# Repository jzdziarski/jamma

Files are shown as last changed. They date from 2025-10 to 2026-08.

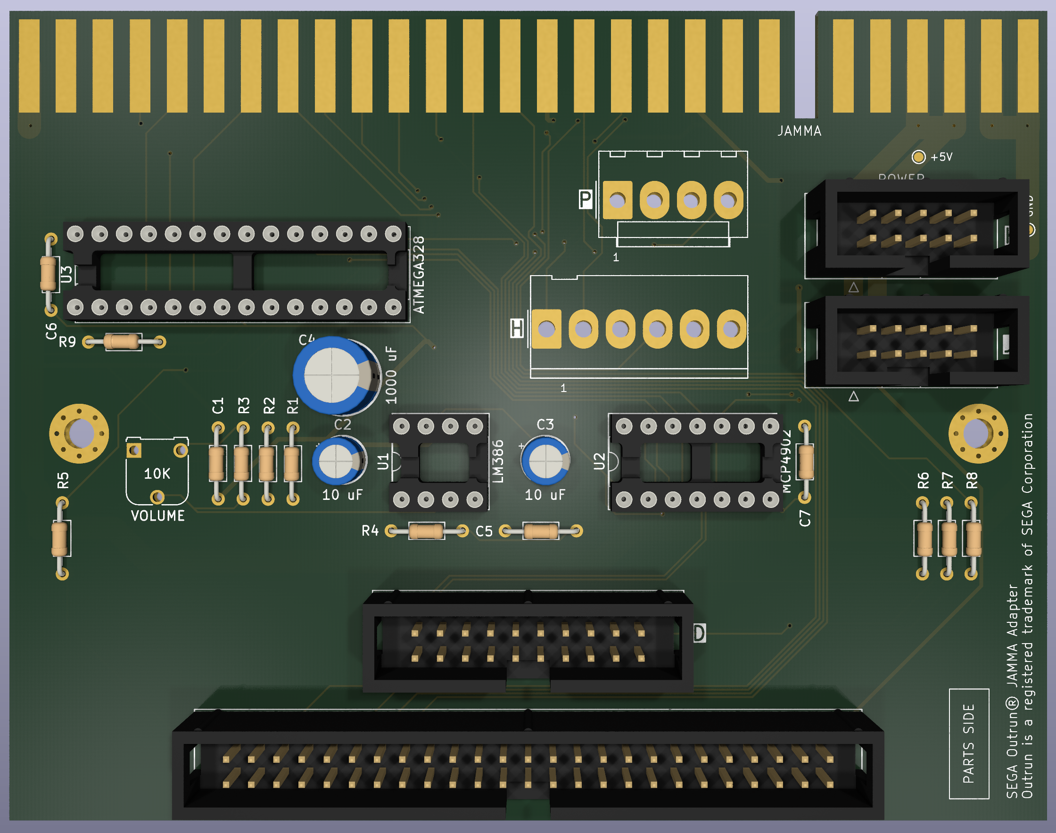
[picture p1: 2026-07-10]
Renderings/outrun_pcb_populated.png

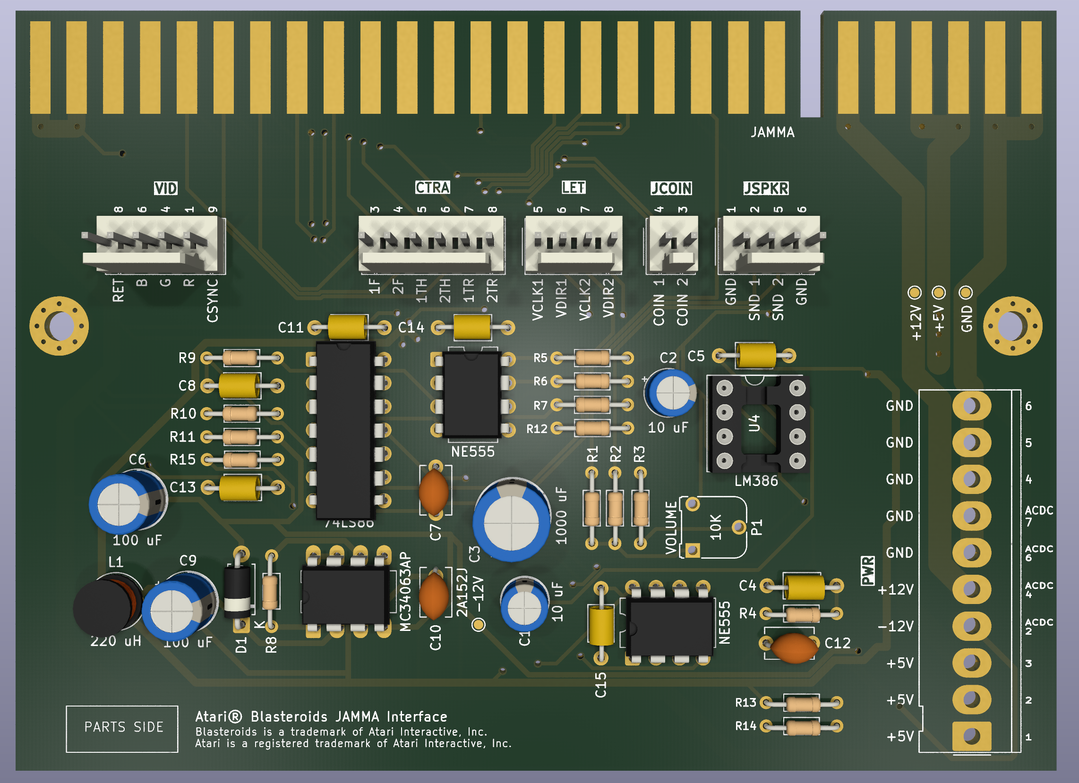
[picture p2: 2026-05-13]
Renderings/blasteroids_pcb_populated.png

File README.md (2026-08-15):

# /jamma
## Arcade JAMMA adapters and interface boards 
License: For non-commercial educational use only

|Subfolder|Description|
|---|---|
|CAD|PCB CAD Files|
|BOM|Bill of Materials (CSV)|
|Microcode|Microcontroller Code|
|Renderings|PCB Renderings|

## PCB Library
|Platform|Title|Tag|Status|
|---|---|---|---|
|Atari System I	|RoadBlasters|ROADBLASTERS_REV_0|Release|
|Atari System I |RoadBlasters|ROADBLASTERS_REV_1|Release|
|Atari System I/II/68K |*|ATARI_REV_0|Release|
|Atari System I/II/68K |*|ATARI_REV_1|Release|
|Blasteroids |Blasteroids|BLASTEROIDS_REV_0|Release|
|Midway MCR III	|Spy Hunter|SPY_HUNTER_REV_0|Release|
|Midway MCR III	|Spy Hunter|SPY_HUNTER_REV_1|Release|
|Midway MCR III |Spy Hunter|SPY_HUNTER_REV_1.1|Development|
|Midway MCR II	|TRON|TRON_REV_0|Release|
|Midway MCR II	|TRON|TRON_REV_1|Release|
|SEGA Super Scaler|Outrun|OUTRUN_REV_0|Release|
|SEGA Super Scaler|Super Hang-On|SUPER_HANG_ON_REV_0|Development|
|Williams System	|*|WILLIAMS_REV_0|Release|
|Williams System |*|WILLIAMS_REV_1|Development|
|Universal Edge	|*|UNIVERSAL_EDGE|Release|
|Universal Interface|*|UNIVERSAL_INTERFACE|Release|
|Universal Microcontroller Interface|*|UNIVERSAL_MICROCONTROLLER|Template|
|Universal Microcontroller Adapter|*|UNIVERSAL_MICROCONTROLLER_ADAPTER|Template|

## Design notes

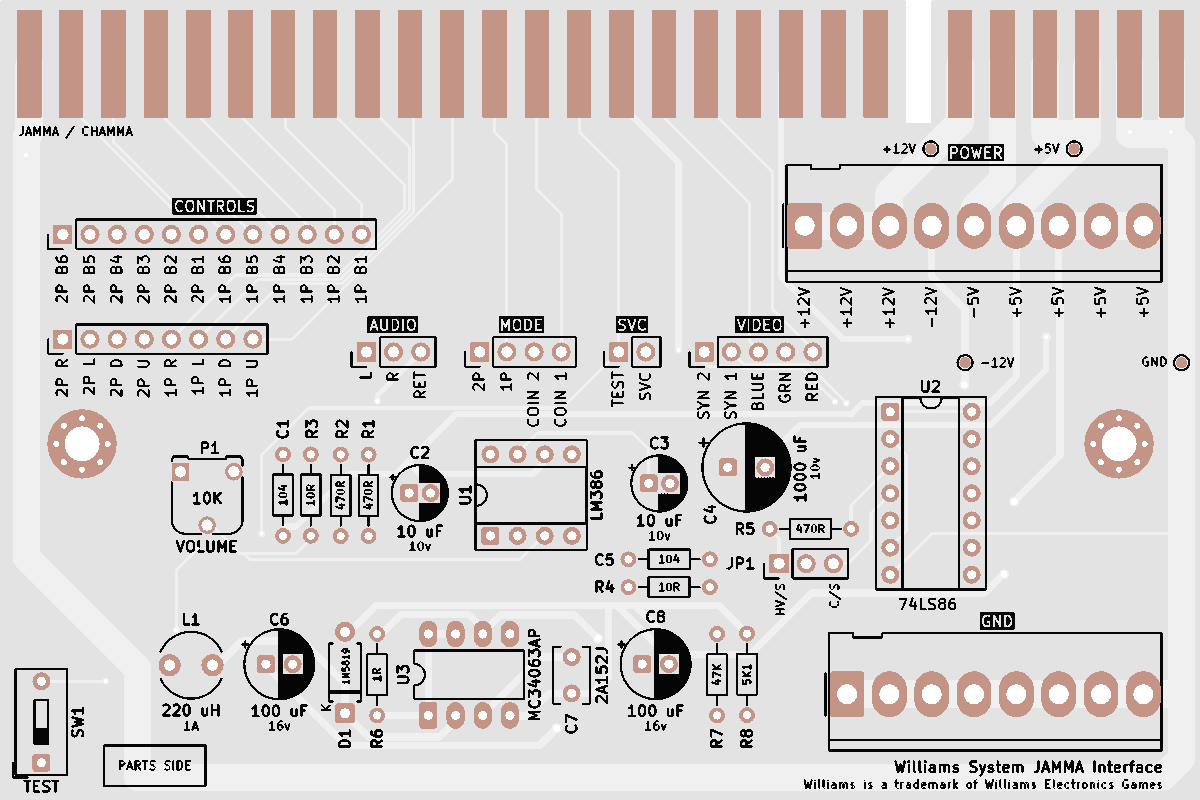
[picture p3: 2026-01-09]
Renderings/williams_pcb.png

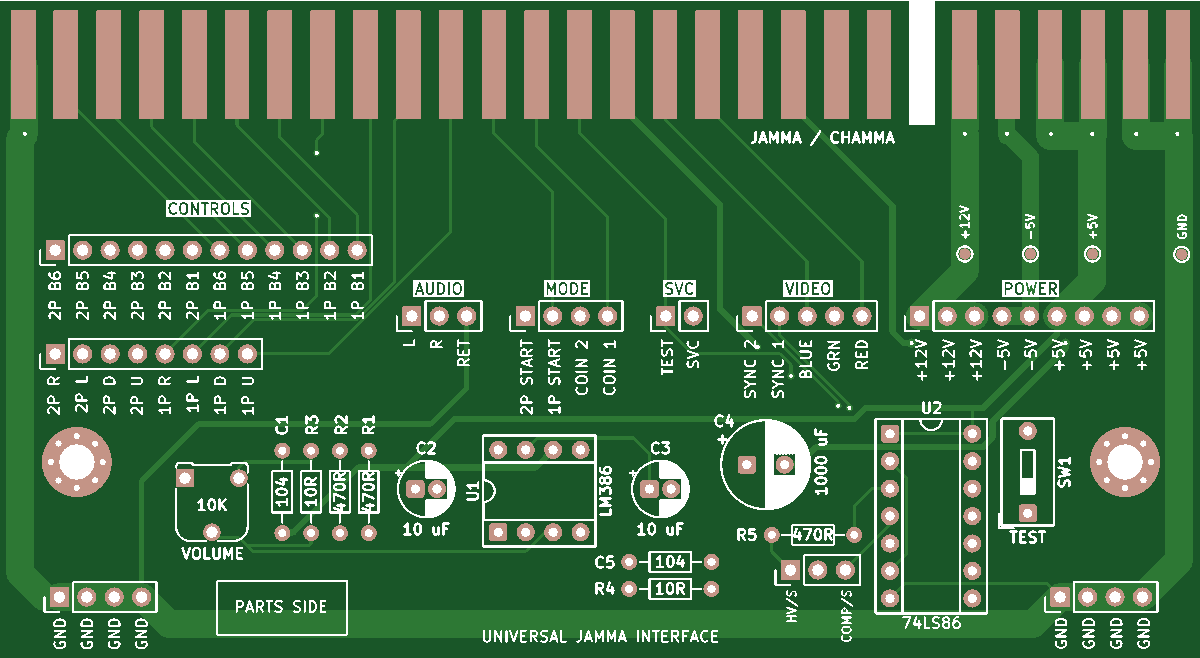
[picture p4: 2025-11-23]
Renderings/universal_jamma_pcb.png

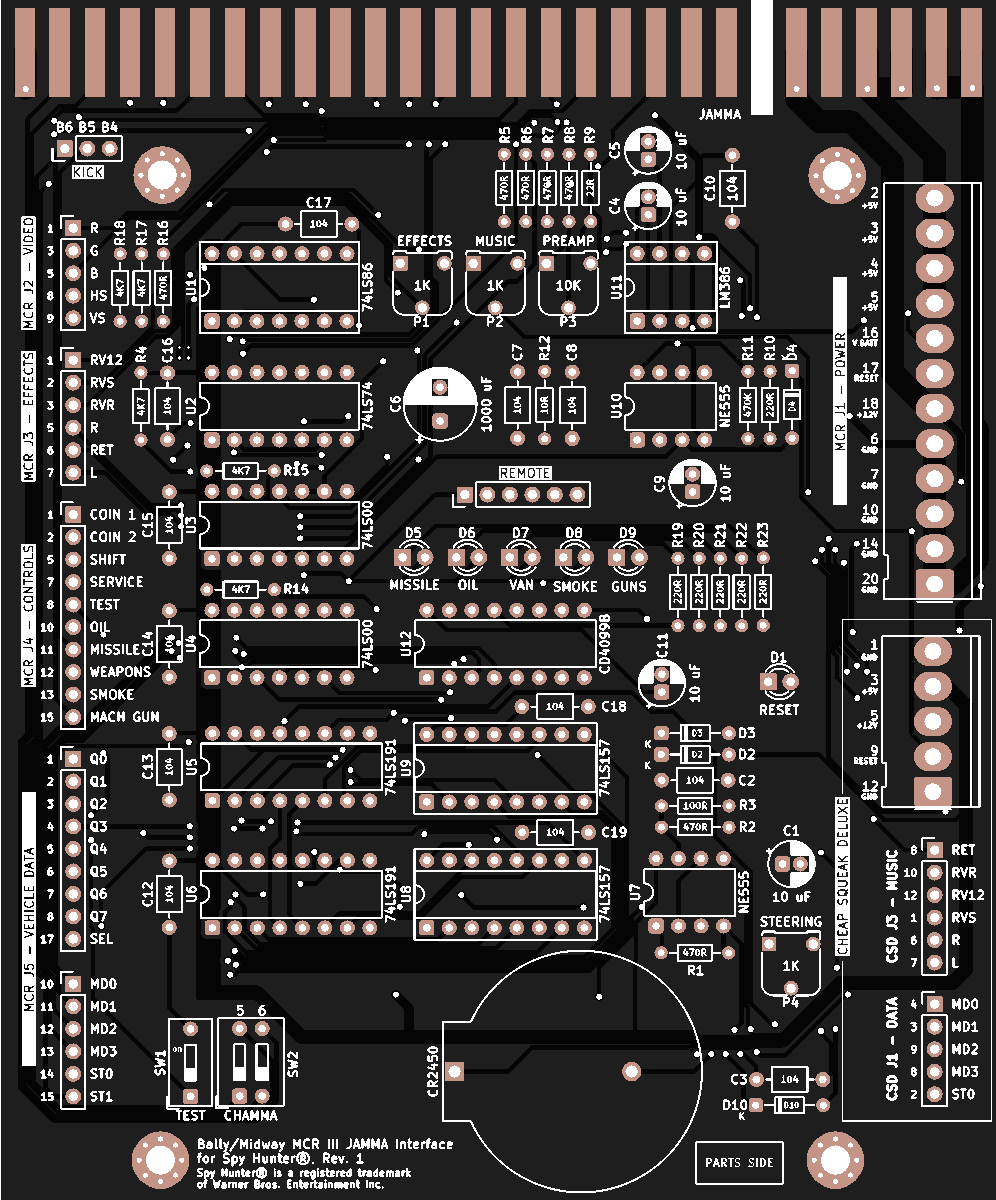
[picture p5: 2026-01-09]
Renderings/spy_hunter_pcb.png

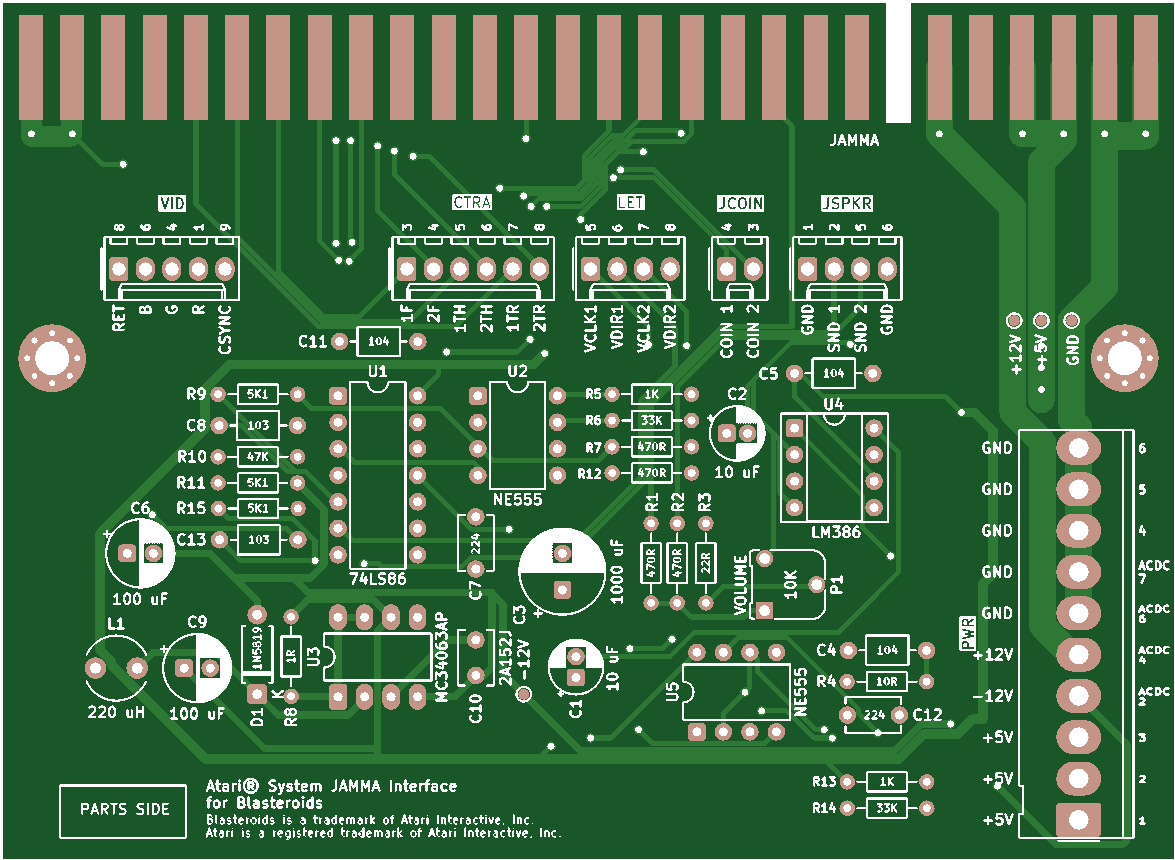
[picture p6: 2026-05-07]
Renderings/blasteroids_pcb.png

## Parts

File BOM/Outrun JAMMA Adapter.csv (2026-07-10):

Outrun JAMMA Adapter BOM
Index | Component | Manufacturer Part Number | Manufacturer Name | Description | Requested Quantity | Pack Quantity 1 | Pack Type 1 | Digi-Key Part Number | Unit Price | Extended Price | Link | Notes
1 | U1 | LM386N-1/NOPB | Texas Instruments | IC AMP CLASS AB MONO 325MW 8DIP | 1 | 1 | Tube | 296-44414-5-ND | 1.05 | $1.05 | https://www.digikey.com/en/products/detail/texas-instruments/LM386N-1-NOPB/6284
2 | U2 | MCP4902-E/P | Microchip Technology | IC DAC 8BIT 14-PDIP | 1 | 1 | Tube | MCP4902-E/P-ND | 1.84 | $1.84 | https://www.digikey.com/en/products/detail/microchip-technology/MCP4902-E-P/2332821
3 | U3 | ATMEGA328-PU | Microchip Technology | IC MCU 8BIT 32KB FLASH 28DIP | 1 | 1 | Tube | ATMEGA328-PU-ND | 2.63 | $2.63 | https://www.digikey.com/en/products/detail/microchip-technology/ATMEGA328-PU/2271026
4 | VOL | PT6KV-103A2020 | Amphenol Piher Sensing Systems | TRIMMER 10K OHM 0.1W PC PIN TOP | 1 | 1 | Bulk | 1993-PT6KV-103A2020-ND | 0.5 | $0.50 | https://www.digikey.com/en/products/detail/amphenol-piher-sensing-systems/PT6KV-103A2020/13244440
5 | R1 / R2 | CFM14JT470R | Stackpole Electronics Inc | RES 470 OHM 5% 1/4W AXIAL | 2 | 2 | Cut Tape (CT) | S470QCT-ND | 0.1 | $0.20 | https://www.digikey.com/en/products/detail/stackpole-electronics-inc/CFM14JT470R/1742224
6 | R3 | CF14JT2K20 | Stackpole Electronics Inc | RES 2.2K OHM 5% 1/4W AXIAL | 1 | 1 | Cut Tape (CT) | CF14JT2K20CT-ND | 0.16 | $0.16 | https://www.digikey.com/en/products/detail/stackpole-electronics-inc/CF14JT2K20/1741321
7 | R3 / R4 | CFM14JT10R0 | Stackpole Electronics Inc | RES 10 OHM 5% 1/4W AXIAL | 2 | 2 | Cut Tape (CT) | S10QCT-ND | 0.1 | $0.20 | https://www.digikey.com/en/products/detail/stackpole-electronics-inc/CFM14JT10R0/1742055
8 | R5-R8 | CFM14JT100R | Stackpole Electronics Inc | RES 100 OHM 5% 1/4W AXIAL | 4 | 4 | Cut Tape (CT) | S100QTR-ND | 0.1 | $0.40 | https://www.digikey.com/en/products/detail/stackpole-electronics-inc/CFM14JT100R/1742057
9 | R9 | CFM14JT10K0 | Stackpole Electronics Inc | RES 10K OHM 5% 1/4W AXIAL | 1 | 1 | Cut Tape (CT) | S10KQTR-ND | 0.1 | $0.10 | https://www.digikey.com/en/products/detail/stackpole-electronics-inc/CFM14JT10K0/1742061
10 | C1 / C5-C7 | C410C104K3R5TA7200 | KEMET | CAP CER 0.1UF 25V X7R AXIAL | 10 | 10 | Cut Tape (CT) | 399-C410C104K3R5TA7200CT-ND | 0.23 | $2.29 | https://www.digikey.com/en/products/detail/kemet/C410C104K3R5TA7200/14681403
11 | C2 / C3 | ESK106M010AC3AA | KEMET | CAP ALUM 10UF 20% 10V RADIAL TH | 2 | 2 | Bulk | 399-ESK106M010AC3AA-ND | 0.21 | $0.42 | https://www.digikey.com/en/products/detail/kemet/ESK106M010AC3AA/13176733
 | C4 | ESY108M010AH2EA | KEMET | CAP ALUM 1000UF 20% 10V RADIAL | 1 | 1 | Bulk | 399-6662-1-ND | 0.65 | $0.65 | https://www.digikey.com/en/products/detail/kemet/ESY108M010AH2EA/3083077
12
13 | U1S | 1-2199298-2 | TE Connectivity | CONN IC DIP SOCKET 8POS TIN | 1 | 1 | Bulk | A120347-ND | 0.22 | $0.22 | https://www.digikey.com/en/products/detail/te-connectivity-amp-connectors/1-2199298-2/5022039
 | U3S | 1-2199298-9 | TE Connectivity | CONN IC DIP SOCKET 28POS TIN1 | 1 | 1 | Bulk | A120353-ND | 1.01 | $1.01 | https://www.digikey.com/en/products/detail/te-connectivity-amp-connectors/1-2199298-9/5022045
14
15 | D | XG4A-2031 | Omron Electronics Inc | CONN HEADER VERT 20POS 2.54MM | 1 | 1 | Tray | OR885-ND | 2.12 | $2.12 | https://www.digikey.com/en/products/detail/omron-electronics-inc-emc-div/XG4A-2031/1787149
16 | G | XG4A-5031 | Omron Electronics Inc | CONN HEADER VERT 50POS 2.54MM | 1 | 1 | Tray | OR894-ND | 3.80 | $3.80 | https://www.digikey.com/en/products/detail/omron-electronics-inc-emc-div/XG4A-5031/1787154
17 | H | 26644060 | Molex | CONN HEADER VERT 6POS 3.96MM | 1 | 1 | Bulk | WM4655-ND | 0.76 | $0.76 | https://www.digikey.com/en/products/detail/molex/0026644060/2002014
18 | J, K | XG4A-1031 | Omron Electronics Inc | CONN HEADER VERT 10POS 2.54MM | 2 | 1 | Tray | OR880-ND | 1.41 | $2.82 | https://www.digikey.com/en/products/detail/omron-electronics-inc-emc-div/XG4A-1031/1787146
19 | P | 26644040 | Molex | CONN HEADER VERT 4POS 3.96MM | 1 | 1 | Bulk | 23-0026644040-ND | 1.29 | $1.29 | https://www.digikey.com/en/products/detail/molex/0026644040/2002012?s=N4IgTCBcDaIAxzANiQFlXDIC6BfIA

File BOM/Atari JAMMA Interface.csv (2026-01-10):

Atari System JAMMA Adapter
Index | Component | Manufacturer Part Number | Manufacturer Name | Description | Requested Quantity | Pack Quantity 1 | Pack Type 1 | Digi-Key Part Number | Unit Price | Extended Price | Link | Notes
1 | U1 | LM386N-1 | Texas Instruments | IC AMP CLASS AB MONO 325MW 8DIP | 1 | 1 | Tube | 296-44414-5-ND | 1.05 | $1.05 | https://www.digikey.com/en/products/detail/texas-instruments/LM386N-1-NOPB/6284
2 | U2 | SN74LS86AN | Texas Instruments | IC GATE XOR 4CH 2-INP 14DIP | 1 | 1 | Tube | 296-1669-5-ND | 0.75 | $0.75 | https://www.digikey.com/en/products/detail/texas-instruments/SN74LS86AN/277315
3 | U3 | MC34063AP | Texas Instruments | IC REG BUCK BOOST ADJ 1.5A 8PDIP | 1 | 1 | Tube | 296-17766-5-ND | 1.36 | $1.36 | https://www.digikey.com/en/products/detail/texas-instruments/MC34063AP/717432
4 | U4 | SN74LS04N | Texas Instruments | IC INVERTER 6CH 1-INP 14DIP | 1 | 1 | Tube | 296-1629-5-ND | 0.91 | $0.91 | https://www.digikey.com/en/products/detail/texas-instruments/SN74LS04N/277275
5 | SW1 | DS04-254-2L-01BK | Same Sky (Formerly CUI Devices) | SWITCH SLIDE DIP SPST 0.025A 24V | 1 | 1 | Tube | 2223-DS04-254-2L-01BK-ND | 0.65 | $0.65 | https://www.digikey.com/en/products/detail/same-sky-formerly-cui-devices/DS04-254-2L-01BK/11310830
6 |  | 22285364 | Molex | CONN HEADER VERT 36POS 2.54MM | 2 | 1 | Bag | WM50034-36-ND | 1.42 | 2.84 | https://www.digikey.com/en/products/detail/molex/0022285364/6167155
7 | POWER | 26481085 | Molex | CONN HEADER VERT 8POS 3.96MM | 1 | 1 | Bulk | WM50008-08-ND | 1.14 | 1.14 | https://www.digikey.com/en/products/detail/molex/0026481085/26767
8 | GND | 26481045 | Molex | CONN HEADER VERT 4POS 3.96MM | 2 | 1 | Bulk | WM50008-04-ND | 0.79 | 1.58 | https://www.digikey.com/en/products/detail/molex/0026481045/26759
9 | P1 | PT6KV-103A2020 | Amphenol Piher Sensing Systems | TRIMMER 10K OHM 0.1W PC PIN TOP | 1 | 1 | Bulk | 1993-PT6KV-103A2020-ND | 0.5 | $0.50 | https://www.digikey.com/en/products/detail/amphenol-piher-sensing-systems/PT6KV-103A2020/13244440
10 | R1 / R2 / R5 | CFM14JT470R | Stackpole Electronics Inc | RES 470 OHM 5% 1/4W AXIAL | 2 | 1 | Cut Tape (CT) | S470QCT-ND | 0.1 | $0.20 | https://www.digikey.com/en/products/detail/stackpole-electronics-inc/CFM14JT470R/1742224
11 | R3 | CFM14JT22R0 | Stackpole Electronics Inc | RES 22 OHM 5% 1/4W AXIAL | 1 | 1 | Cut Tape (CT) | S22QCT-ND | 0.1 | $0.10 | https://www.digikey.com/en/products/detail/stackpole-electronics-inc/CFM14JT22R0/1742137
12 | R4 | CFM14JT10R0 | Stackpole Electronics Inc | RES 10 OHM 5% 1/4W AXIAL | 1 | 1 | Cut Tape (CT) | S10QCT-ND | 0.1 | $0.10 | https://www.digikey.com/en/products/detail/stackpole-electronics-inc/CFM14JT10R0/1742055
13 | R6 | CFM14JT1R00 | Stackpole Electronics Inc | RES 1 OHM 5% 1/4W AXIAL | 1 | 1 | Cut Tape (CT) | S1QCT-ND | 0.1 | $0.10 | https://www.digikey.com/en/products/detail/stackpole-electronics-inc/cfm14jt1r00/1742027
14 | R7 | CFM14JT47K0 | Stackpole Electronics Inc | RES 47K OHM 5% 1/4W AXIAL | 1 | 1 | Cut Tape (CT) | S47KQCT-ND | 0.1 | $0.10 | https://www.digikey.com/en/products/detail/stackpole-electronics-inc/cfm14jt47k0/1742228
15 | R8 | CFM14JT5K10 | Stackpole Electronics Inc | RES 5.1K OHM 5% 1/4W AXIAL | 1 | 1 | Cut Tape (CT) | S5.1KQCT-ND | 0.1 | $0.10 | https://www.digikey.com/en/products/detail/stackpole-electronics-inc/CFM14JT5K10/1742231
16 | C1 / C5 | C410C104K3R5TA7200 | KEMET | CAP CER 0.1UF 25V X7R AXIAL | 2 | 1 | Cut Tape (CT) | 399-C410C104K3R5TA7200CT-ND | 0.23 | $0.46 | https://www.digikey.com/en/products/detail/kemet/C410C104K3R5TA7200/14681403
17 | C2 / C3 | ESK106M010AC3AA | KEMET | CAP ALUM 10UF 20% 10V RADIAL TH | 2 | 1 | Bulk | 399-ESK106M010AC3AA-ND | 0.21 | $0.42 | https://www.digikey.com/en/products/detail/kemet/ESK106M010AC3AA/13176733
18 | C4 | ESY108M010AH2EA | KEMET | CAP ALUM 1000UF 20% 10V RADIAL | 1 | 1 | Bulk | 399-6662-1-ND | 0.65 | $0.65 | https://www.digikey.com/en/products/detail/kemet/ESY108M010AH2EA/3083077
19 | C6 / C8 | ESK107M016AC3AA | KEMET | CAP ALUM 100UF 20% 16V RADIAL TH | 2 | 1 | Bulk | 399-6601-ND | 0.17 | $0.34 | https://www.digikey.com/en/products/detail/kemet/ESK107M016AC3AA/3083016
20 | C7 | QYX2A152JTP | Nichicon | CAP FILM 1500PF 5% 100VDC RADIAL | 1 | 1 | Bulk | 493-3478-ND | 0.42 | 0.42 | https://www.digikey.com/en/products/detail/nichicon/QYX2A152JTP/2117767
21 | L1 | RLB9012-221KL | Bourns, Inc. | FIXED IND 220UH 1A 650 MOHM TH | 1 | 1 | Bulk | RLB9012-221KL-ND | 0.58 | 0.58 | https://www.digikey.com/en/products/detail/bourns-inc/RLB9012-221KL/1969608
22 | D1 | 1N5819G | onsemi | DIODE SCHOTTKY 40V 1A AXIAL | 1 | 1 | Bulk | 1N5819GOS-ND | 0.23 | $0.23 | https://www.digikey.com/en/products/detail/onsemi/1N5819G/1474211

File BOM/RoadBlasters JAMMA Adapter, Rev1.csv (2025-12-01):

RoadBlasters JAMMA Adapter
Index | Component | Manufacturer Part Number | Manufacturer Name | Description | Requested Quantity | Pack Quantity 1 | Pack Type 1 | Digi-Key Part Number | Unit Price | Extended Price | Link | Notes
1 | U1 | SN74LS86AN | Texas Instruments | IC GATE XOR 4CH 2-INP 14DIP | 1 | 1 | Tube | 296-1669-5-ND | 0.75 | $0.75 | https://www.digikey.com/en/products/detail/texas-instruments/SN74LS86AN/277315
2 | U2 | NE555P | Texas Instruments | IC OSC SINGLE TIMER 100KHZ 8-DIP | 1 | 2 | Tube | 296-NE555P-ND | 0.51 | $0.51 | https://www.digikey.com/en/products/detail/texas-instruments/NE555P/277057
3 | U3 | MC34063AP | Texas Instruments | IC REG BUCK BOOST ADJ 1.5A 8PDIP | 1 | 1 | Tube | 296-17766-5-ND | 1.36 | $1.36 | https://www.digikey.com/en/products/detail/texas-instruments/MC34063AP/717432
4 | U4 | LM386N-1/NOPB | Texas Instruments | IC AMP CLASS AB MONO 325MW 8DIP | 1 | 1 | Tube | 296-44414-5-ND | 1.05 | $1.05 | https://www.digikey.com/en/products/detail/texas-instruments/LM386N-1-NOPB/6284
5 | SW1 | DS04-254-2L-01BK | Same Sky (Formerly CUI Devices) | SWITCH SLIDE DIP SPST 0.025A 24V | 1 | 1 | Tube | 2223-DS04-254-2L-01BK-ND | 0.65 | $0.65 | https://www.digikey.com/en/products/detail/same-sky-formerly-cui-devices/DS04-254-2L-01BK/11310830
6 | J102-J108 | 22284361 | Molex | CONN HEADER VERT 36POS 2.54MM | 1 | 1 | Bag | WM50017-36-ND | 1.23 | $1.23 | https://www.digikey.com/en/products/detail/molex/0022284361/313891
7 | P1 | PT6KV-103A2020 | Amphenol Piher Sensing Systems | TRIMMER 10K OHM 0.1W PC PIN TOP | 1 | 1 | Bulk | 1993-PT6KV-103A2020-ND | 0.5 | $0.50 | https://www.digikey.com/en/products/detail/amphenol-piher-sensing-systems/PT6KV-103A2020/13244440
11 | R1 / R2 / R7 | CFM14JT470R | Stackpole Electronics Inc | RES 470 OHM 5% 1/4W AXIAL | 2 | 2 | Cut Tape (CT) | S470QCT-ND | 0.1 | $0.20 | https://www.digikey.com/en/products/detail/stackpole-electronics-inc/CFM14JT470R/1742224 | 510 R acceptable
12 | R3 | CFM14JT22R0 | Stackpole Electronics Inc | RES 22 OHM 5% 1/4W AXIAL | 1 | 1 | Cut Tape (CT) | S22QCT-ND | 0.1 | $0.10 | https://www.digikey.com/en/products/detail/stackpole-electronics-inc/CFM14JT22R0/1742137
13 | R4 | CFM14JT10R0 | Stackpole Electronics Inc | RES 10 OHM 5% 1/4W AXIAL | 1 | 1 | Cut Tape (CT) | S10QCT-ND | 0.1 | $0.10 | https://www.digikey.com/en/products/detail/stackpole-electronics-inc/CFM14JT10R0/1742055
14 | R5 | CFM14JT1K00 | Stackpole Electronics Inc | RES 1K OHM 5% 1/4W AXIAL | 1 | 1 | Cut Tape (CT) | S1KQCT-ND | 0.1 | $0.10 | https://www.digikey.com/en/products/detail/stackpole-electronics-inc/CFM14JT1K00/1742111
15 | R6 | CFM14JT33K0 | Stackpole Electronics Inc | RES 33K OHM 5% 1/4W AXIAL | 1 | 1 | Cut Tape (CT) | S33KQCT-N | 0.1 | $0.10 | https://www.digikey.com/en/products/detail/stackpole-electronics-inc/cfm14jt33k0/1742191
16 | R9 / R11 | CFM14JT5K10 | Stackpole Electronics Inc | RES 5.1K OHM 5% 1/4W AXIAL | 2 | 2 | Cut Tape (CT) | S5.1KQCT-NDÊ | 0.1 | $0.20 | https://www.digikey.com/en/products/detail/stackpole-electronics-inc/CFM14JT5K10/1742231
17 | R8 | CFM14JT1R00 | Stackpole Electronics Inc | RES 1 OHM 5% 1/4W AXIAL | 1 | 1 | Cut Tape (CT) | S1QCT-ND | 0.1 | $0.10 | https://www.digikey.com/en/products/detail/stackpole-electronics-inc/cfm14jt1r00/1742027
18 | R10 | CFM14JT47K0 | Stackpole Electronics Inc | RES 47K OHM 5% 1/4W AXIAL | 1 | 1 | Cut Tape (CT) | S47KQCT-NDÊ | 0.1 | $0.10 | https://www.digikey.com/en/products/detail/stackpole-electronics-inc/cfm14jt47k0/1742228
19 | C1 / C2 | ESK106M010AC3AA | KEMET | CAP ALUM 10UF 20% 10V RADIAL TH | 2 | 2 | Bulk | 399-ESK106M010AC3AA-ND | 0.21 | $0.42 | https://www.digikey.com/en/products/detail/kemet/ESK106M010AC3AA/13176733
20 | C3 | ESY108M010AH2EA | KEMET | CAP ALUM 1000UF 20% 10V RADIAL | 1 | 1 | Bulk | 399-6662-1-ND | 0.65 | $0.65 | https://www.digikey.com/en/products/detail/kemet/ESY108M010AH2EA/3083077
21 | C4 / C5 | C410C104K3R5TA7200 | KEMET | CAP CER 0.1UF 25V X7R AXIAL | 10 | 10 | Cut Tape (CT) | 399-C410C104K3R5TA7200CT-ND | 0.23 | $2.29 | https://www.digikey.com/en/products/detail/kemet/C410C104K3R5TA7200/14681403
22 | C6 / C9 | ESK107M016AC3AA | KEMET | CAP ALUM 100UF 20% 16V RADIAL TH | 2 | 2 | Bulk | 399-6601-ND | 0.17 | $0.34 | https://www.digikey.com/en/products/detail/kemet/ESK107M016AC3AA/3083016
23 | C7 | C330C224J3H5TA91707301 | KEMET | CAP CER 0.22UF 25V X8R RADIAL | 1 | 1 | Cut Tape (CT) | 399-14397-1-ND | 1.1 | $1.10 | https://www.digikey.com/en/products/detail/kemet/C330C224J3H5TA91707301/6919003
24 | C8 | C430C103K3G5TA | KEMET | CAP CER 10000PF 25V C0G AXIAL | 1 | 1 | Bulk | C430C103K3G5TA-ND | 0.36 | $0.36 | https://www.digikey.com/en/products/detail/kemet/C430C103K3G5TA/6687833
25 | C10 | C322C152K5R5TA | KEMET | CAP CER 1500PF 50V X7R RADIAL | 1 | 1 | Bulk | 399-9800-ND | 0.31 | $0.31 | https://www.digikey.com/en/products/detail/kemet/C322C152K5R5TA/3726139 | Use film cap to reduce noise
26 | L1 | SBC1-221-391 | KEMET | FIXED IND 220UH 390MA 1.2 OHM TH | 1 | 1 | Bulk | 399-20737-ND | 0.69 | $0.69 | https://www.digikey.com/en/products/detail/kemet/SBC1-221-391/10062547
27 | D1 | 1N5819G | onsemi | DIODE SCHOTTKY 40V 1A AXIAL | 1 | 1 | Bulk | 1N5819GOS-ND | 0.23 | $0.23 | https://www.digikey.com/en/products/detail/onsemi/1N5819G/1474211
28 | U4S | 1-2199298-2 | TE Connectivity | CONN IC DIP SOCKET 8POS TIN | 1 | 1 | Bulk | A120347-ND | 0.22 | $0.22 | https://www.digikey.com/en/products/detail/te-connectivity-amp-connectors/1-2199298-2/5022039
29 | J101 | 26481105 | Molex | CONN HEADER VERT 10POS 3.96MM | 1 | 1 | Bulk | WM50008-10-ND | 1.33 | $1.33 | https://www.digikey.com/en/products/detail/molex/0026481105/26771

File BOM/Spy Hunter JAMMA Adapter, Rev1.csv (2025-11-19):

Spy Hunter JAMMA Adapter
Index | Component | Manufacturer Part Number | Manufacturer Name | Description | Requested Quantity | Pack Quantity 1 | Pack Type 1 | Digi-Key Part Number | Unit Price | Extended Price | Link | Notes
1 | U1 | SN74LS86AN | Texas Instruments | IC GATE XOR 4CH 2-INP 14DIP | 1 | 1 | Tube | 296-1669-5-ND | 0.75 | $0.75 | https://www.digikey.com/en/products/detail/texas-instruments/SN74LS86AN/277315
2 | U2 | SN74LS74AN | Texas Instruments | IC FF D-TYPE DOUBLE 1BIT 14PDIP | 1 | 1 | Tube | 296-1668-5-ND | 0.75 | $0.75 | https://www.digikey.com/en/products/detail/texas-instruments/SN74LS74AN/277314
3 | U3 U4 | SN74LS00N | Texas Instruments | IC GATE NAND 4CH 2-INP 14DIP | 2 | 1 | Tube | 296-1626-ND | 0.76 | $1.52 | https://www.digikey.com/en/products/detail/texas-instruments/SN74LS00N/277272
4 | U5 U6 | SN74LS191N | Texas Instruments | IC BINARY COUNTER 4-BIT 16DIP | 2 | 1 | Tube | 296-14886-5-ND | 1.58 | $3.16 | https://www.digikey.com/en/products/detail/texas-instruments/SN74LS191N/563041
5 | U7 U10 | NE555P | Texas Instruments | IC OSC SINGLE TIMER 100KHZ 8-DIP | 2 | 2 | Tube | 296-NE555P-ND | 0.51 | $1.02 | https://www.digikey.com/en/products/detail/texas-instruments/NE555P/277057
6 | U8 U9 | SN74LS157N | Texas Instruments | IC MULTIPLEXER 4 X 2:1 16-PDIP | 2 | 1 | Tube | 296-1645-5-ND | 1.02 | $2.04 | https://www.digikey.com/en/products/detail/texas-instruments/SN74LS157N/277291
7 | U11 | LM386N-1/NOPB | Texas Instruments | IC AMP CLASS AB MONO 325MW 8DIP | 1 | 1 | Tube | 296-44414-5-ND | 1.05 | $1.05 | https://www.digikey.com/en/products/detail/texas-instruments/LM386N-1-NOPB/6284
8 | U12 | CD4099BE | Texas Instruments | IC D-TYPE ADDR 1:8 16-PDIP | 1 | 1 | Tube | 296-2070-5-ND | 1.22 | $1.22 | https://www.digikey.com/en/products/detail/texas-instruments/CD4099BE/67333
9 | SW1 | DS04-254-2L-01BK | Same Sky (Formerly CUI Devices) | SWITCH SLIDE DIP SPST 0.025A 24V | 1 | 1 | Tube | 2223-DS04-254-2L-01BK-ND | 0.65 | $0.65 | https://www.digikey.com/en/products/detail/same-sky-formerly-cui-devices/DS04-254-2L-01BK/11310830
10 | SW2 | DS04-254-2L-02BK | Same Sky (Formerly CUI Devices) | SWITCH SLIDE DIP SPST 0.025A 24V | 1 | 1 | Tube | 2223-DS04-254-2L-02BK-ND | $0.62 | $0.62 | https://www.digikey.com/en/products/detail/same-sky-formerly-cui-devices-/DS04-254-2L-02BK/11310854
11 | MCR J2-J5, CSD J1, CSD J3, EXT, REMOTE | 22284361 | Molex | CONN HEADER VERT 36POS 2.54MM | 3 | 1 | Bag | WM50017-36-ND | 3.69 | $4.92 | https://www.digikey.com/en/products/detail/molex/0022284361/313891
12 | MCR J1 | 26481125 | Molex | CONN HEADER VERT 12POS 3.96MM | 1 | 1 | Bulk | WM50008-12-ND | 1.53 | $1.53 | https://www.digikey.com/en/products/detail/molex/0026481125/26775 | Gold plating 0416710011
13 | CSD J2 | 26481055 | Molex | CONN HEADER VERT 5POS 3.96MM | 1 | 1 | Bulk | WM50008-05-ND | 0.83 | $0.83 | https://www.digikey.com/en/products/detail/molex/0026481055/26761 | Gold plating 0416710027
14 | P1 P2 P4 | PT6KV-102A2020 | Amphenol Piher Sensing Systems | TRIMMER 1K OHM 0.1W PC PIN TOP | 3 | 1 | Bulk | 1993-1043-ND | 0.69 | $2.07 | https://www.digikey.com/en/products/detail/amphenol-piher-sensing-systems/PT6KV-102A2020/9555881
15 | P3 | PT6KV-103A2020 | Amphenol Piher Sensing Systems | TRIMMER 10K OHM 0.1W PC PIN TOP | 1 | 1 | Bulk | 1993-PT6KV-103A2020-ND | 0.5 | $0.50 | https://www.digikey.com/en/products/detail/amphenol-piher-sensing-systems/PT6KV-103A2020/13244440
16 | R1, R2, R5-R8, R16 | CFM14JT470R | Stackpole Electronics Inc | RES 470 OHM 5% 1/4W AXIAL | 7 | 1 | Cut Tape (CT) | S470QCT-ND | 0.1 | $0.70 | https://www.digikey.com/en/products/detail/stackpole-electronics-inc/CFM14JT470R/1742224 | 510 R acceptable
17 | R9 | CFM14JT22R0 | Stackpole Electronics Inc | RES 22 OHM 5% 1/4W AXIAL | 1 | 1 | Cut Tape (CT) | S22QCT-ND | 0.1 | $0.10 | https://www.digikey.com/en/products/detail/stackpole-electronics-inc/CFM14JT22R0/1742137
18 | R12 | CFM14JT10R0 | Stackpole Electronics Inc | RES 10 OHM 5% 1/4W AXIAL | 1 | 1 | Cut Tape (CT) | S10QCT-ND | 0.1 | $0.10 | https://www.digikey.com/en/products/detail/stackpole-electronics-inc/CFM14JT10R0/1742055
19 | R4, R14-R18 | CFM14JT4K70 | Stackpole Electronics Inc | RES 4.7K OHM 5% 1/4W AXIAL | 8 | 1 | Cut Tape (CT) | S4.7KQCT-ND | 0.1 | $0.80 | https://www.digikey.com/en/products/detail/stackpole-electronics-inc/CFM14JT4K70/1742213
20 | R11 | CFM14JT470K | Stackpole Electronics Inc | RES 470K OHM 5% 1/4W AXIAL | 1 | 1 | Cut Tape (CT) | S470KQCT-ND | 0.1 | $0.10 | https://www.digikey.com/en/products/detail/stackpole-electronics-inc/CFM14JT470K/1742226
21 | R3 | CFM14JT100R | Stackpole Electronics Inc | RES 100 OHM 5% 1/4W AXIAL | 1 | 1 | Cut Tape (CT) | S100QCT-ND | 0.1 | $0.10 | https://www.digikey.com/en/products/detail/stackpole-electronics-inc/CFM14JT100R/1742057
22 | R10, R19-R23 | CFM14JT220R | Stackpole Electronics Inc | RES 220 OHM 5% 1/4W AXIAL | 6 | 1 | Cut Tape (CT) | S220QCT-ND | 0.1 | $0.60 | https://www.digikey.com/en/products/detail/stackpole-electronics-inc/CFM14JT200R/1742132
23 | D1, D5-9 | LTL-307EE | Lite-On Inc. | LED RED CLEAR T-1 3/4 T/H | 6 | 1 | Bulk | 160-1701-ND | 0.19 | $1.14 | https://www.digikey.com/en/products/detail/liteon/LTL-307EE/140833
24 | D2 / D3 | 1N5817RLG | onsemi | DIODE SCHOTTKY 20V 1A AXIAL | 2 | 1 | Cut Tape (CT) | 1N5817RLGOSCT-ND | 0.41 | $0.82 | https://www.digikey.com/en/products/detail/onsemi/1N5817RLG/807250
25 | D4, D10 | 1N4148TR | onsemi | DIODE STANDARD 100V 200MA DO35 | 2 | 1 | Cut Tape (CT) | 1N4148FSCT-ND | 0.1 | $0.20 | https://www.digikey.com/en/products/detail/onsemi/1N4148TR/458811
26 | C1 C4 C5 C9 C11 | ESK106M010AC3AA | KEMET | CAP ALUM 10UF 20% 10V RADIAL TH | 5 | 1 | Bulk | 399-ESK106M010AC3AA-ND | 0.21 | $0.84 | https://www.digikey.com/en/products/detail/kemet/ESK106M010AC3AA/13176733
27 | C2 C3 C7 C8 C10, C12-C19 | C410C104K3R5TA7200 | KEMET | CAP CER 0.1UF 25V X7R AXIAL | 20 | 10 | Cut Tape (CT) | 399-C410C104K3R5TA7200CT-ND | 0.23 | $4.58 | https://www.digikey.com/en/products/detail/kemet/C410C104K3R5TA7200/14681403
28 | C6 | ESY108M010AH2EA | KEMET | CAP ALUM 1000UF 20% 10V RADIAL | 1 | 1 | Bulk | 399-6662-1-ND | 0.65 | $0.65 | https://www.digikey.com/en/products/detail/kemet/ESY108M010AH2EA/3083077
29 | CR2450 | 1053 | Keystone | BATT HOLDER COIN 24.5MM PC PIN | 1 | 1 | Bulk | 36-1053-ND | 1.42 | $1.42 | https://www.digikey.com/en/products/detail/keystone-electronics/1053/2745672

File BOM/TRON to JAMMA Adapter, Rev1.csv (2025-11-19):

TRON to JAMMA Adapter
Index | Component | Manufacturer Part Number | Manufacturer Name | Description | Requested Quantity | Pack Quantity 1 | Pack Type 1 | Digi-Key Part Number | Unit Price | Extended Price | Link | Notes
1 | U1 | SN74LS86AN | Texas Instruments | IC GATE XOR 4CH 2-INP 14DIP | 1 | 1 | Tube | 296-1669-5-ND | 0.75 | $0.75 | https://www.digikey.com/en/products/detail/texas-instruments/SN74LS86AN/277315
2 | U2A / U2B | SN74LS191N | Texas Instruments | IC BINARY COUNTER 4-BIT 16DIP | 2 |  | Tube | 296-14886-5-ND | 1.58 | $3.16 | https://www.digikey.com/en/products/detail/texas-instruments/SN74LS191N/563041
3 | U3 / U5 | NE555P | Texas Instruments | IC OSC SINGLE TIMER 100KHZ 8-DIP | 2 | 2 | Tube | 296-NE555P-ND | 0.51 | $1.02 | https://www.digikey.com/en/products/detail/texas-instruments/NE555P/277057
4 | U4 | LM386N-1/NOPB | Texas Instruments | IC AMP CLASS AB MONO 325MW 8DIP | 1 | 1 | Tube | 296-44414-5-ND | 1.05 | $1.05 | https://www.digikey.com/en/products/detail/texas-instruments/LM386N-1-NOPB/6284
5 | SW1 | DS04-254-2L-01BK | Same Sky (Formerly CUI Devices) | SWITCH SLIDE DIP SPST 0.025A 24V | 1 | 1 | Tube | 2223-DS04-254-2L-01BK-ND | 0.65 | $0.65 | https://www.digikey.com/en/products/detail/same-sky-formerly-cui-devices/DS04-254-2L-01BK/11310830
7 | JP1 / JP2 | 901310780 | Molex | CONN HEADER VERT 40POS 2.54MM | 1 | 1 | Bulk | WM8152-ND | 4.03 | $4.03 | https://www.digikey.com/en/products/detail/molex/0901310780/760866
8 | JP1S / JP2S | 60900213421 | Wurth Electronik | JUMPER W/TEST PNT 1X2PINS 2.54MM | 2 |  | Bag | 732-2678-ND | 0.28 | $0.56 | https://www.digikey.com/en/products/detail/w-rth-elektronik/60900213421/2508447
9 | J2 - J5 | 22284361 | Molex | CONN HEADER VERT 36POS 2.54MM | 1 | 1 | Bag | WM50017-36-ND | 1.23 | $1.23 | https://www.digikey.com/en/products/detail/molex/0022284361/313891
10 | J1 | 26605120 | Molex | CONN HEADER R/A 12POS 3.96MM | 1 | 1 | Bulk | 23-0026605120-ND | 0.94 | $0.94 | https://www.digikey.com/en/products/detail/molex/0026605120/190695 | Straight is 26604120
11 | P1 / P3 | PT6KV-102A2020 | Amphenol Piher Sensing Systems | TRIMMER 1K OHM 0.1W PC PIN TOP | 2 | 2 | Bulk | 1993-1043-ND | 0.69 | $1.38 | https://www.digikey.com/en/products/detail/amphenol-piher-sensing-systems/PT6KV-102A2020/9555881
12 | P2 | PT6KV-103A2020 | Amphenol Piher Sensing Systems | TRIMMER 10K OHM 0.1W PC PIN TOP | 1 | 1 | Bulk | 1993-PT6KV-103A2020-ND | 0.5 | $0.50 | https://www.digikey.com/en/products/detail/amphenol-piher-sensing-systems/PT6KV-103A2020/13244440
13 | R1 / R2 / R8 / R12 | CFM14JT470R | Stackpole Electronics Inc | RES 470 OHM 5% 1/4W AXIAL | 3 | 3 | Cut Tape (CT) | S470QCT-ND | 0.1 | $0.30 | https://www.digikey.com/en/products/detail/stackpole-electronics-inc/CFM14JT470R/1742224 | 510 R acceptable
14 | R3 | CFM14JT22R0 | Stackpole Electronics Inc | RES 22 OHM 5% 1/4W AXIAL | 1 | 1 | Cut Tape (CT) | S22QCT-ND | 0.1 | $0.10 | https://www.digikey.com/en/products/detail/stackpole-electronics-inc/CFM14JT22R0/1742137
15 | R4 | CFM14JT10R0 | Stackpole Electronics Inc | RES 10 OHM 5% 1/4W AXIAL | 1 | 1 | Cut Tape (CT) | S10QCT-ND | 0.1 | $0.10 | https://www.digikey.com/en/products/detail/stackpole-electronics-inc/CFM14JT10R0/1742055
16 | R5 / R11 | CFM14JT4K70 | Stackpole Electronics Inc | RES 4.7K OHM 5% 1/4W AXIAL | 2 | 1 | Cut Tape (CT) | S4.7KQCT-ND | 0.1 | $0.20 | https://www.digikey.com/en/products/detail/stackpole-electronics-inc/CFM14JT4K70/1742213
17 | R6 | CFM14JT470K | Stackpole Electronics Inc | RES 470K OHM 5% 1/4W AXIAL | 1 | 1 | Cut Tape (CT) | S470KQCT-ND | 0.1 | $0.10 | https://www.digikey.com/en/products/detail/stackpole-electronics-inc/CFM14JT470K/1742226
18 | R7 | CFM14JT100R | Stackpole Electronics Inc | RES 100 OHM 5% 1/4W AXIAL | 1 | 1 | Cut Tape (CT) | S100QCT-ND | 0.1 | $0.10 | https://www.digikey.com/en/products/detail/stackpole-electronics-inc/CFM14JT100R/1742057
19 | R9 | CFM14JT100K | Stackpole Electronics Inc | RES 100K OHM 5% 1/4W AXIAL | 1 | 1 | Cut Tape (CT) | S100KQCT-ND | 0.1 | $0.10 | https://www.digikey.com/en/products/detail/stackpole-electronics-inc/CFM14JT100K/1742059
20 | R10 | CFM14JT200R | Stackpole Electronics Inc | RES 200 OHM 5% 1/4W AXIAL | 2 | 2 | Cut Tape (CT) | S200QCT-ND | 0.1 | $0.20 | https://www.digikey.com/en/products/detail/stackpole-electronics-inc/CFM14JT200R/1742132
21 | D1 | 1N4148TR | onsemi | DIODE STANDARD 100V 200MA DO35 | 1 | 1 | Cut Tape (CT) | 1N4148FSCT-ND | 0.1 | $0.10 | https://www.digikey.com/en/products/detail/onsemi/1N4148TR/458811
22 | D2 / D3 | 1N5817RLG | onsemi | DIODE SCHOTTKY 20V 1A AXIAL | 2 | 2 | Cut Tape (CT) | 1N5817RLGOSCT-ND | 0.41 | $0.82 | https://www.digikey.com/en/products/detail/onsemi/1N5817RLG/807250
23 | D4 | LTL-307EE | Lite-On Inc. | LED RED CLEAR T-1 3/4 T/H | 1 | 1 | Bulk | 160-1701-ND | 0.19 | $0.19 | https://www.digikey.com/en/products/detail/liteon/LTL-307EE/140833
24 | C1, 3, 4, 8 | ESK106M010AC3AA | KEMET | CAP ALUM 10UF 20% 10V RADIAL TH | 4 | 4 | Bulk | 399-ESK106M010AC3AA-ND | 0.21 | $0.84 | https://www.digikey.com/en/products/detail/kemet/ESK106M010AC3AA/13176733
25 | C2, 6, 7, 9, 10, 11, 12 | C410C104K3R5TA7200 | KEMET | CAP CER 0.1UF 25V X7R AXIAL | 10 | 10 | Cut Tape (CT) | 399-C410C104K3R5TA7200CT-ND | 0.23 | $2.29 | https://www.digikey.com/en/products/detail/kemet/C410C104K3R5TA7200/14681403
26 | C5 | ESY108M010AH2EA | KEMET | CAP ALUM 1000UF 20% 10V RADIAL | 1 | 1 | Bulk | 399-6662-1-ND | 0.65 | $0.65 | https://www.digikey.com/en/products/detail/kemet/ESY108M010AH2EA/3083077
27 | U1S | 1-2199298-3 | TE Connectivity | CONN IC DIP SOCKET 14POS TIN | 1 | 1 | Bulk | A120348-ND | 0.23 | $0.23 | https://www.digikey.com/en/products/detail/te-connectivity-amp-connectors/1-2199298-3/5022040
28 | U2S | 1-2199298-8 | TE Connectivity | CONN IC DIP SOCKET 24POS TIN | 1 | 1 | Bulk | A120352-ND | 0.72 | $0.72 | https://www.digikey.com/en/products/detail/te-connectivity-amp-connectors/1-2199298-8/5022044
29 | U3S / U4S / U5S | 1-2199298-2 | TE Connectivity | CONN IC DIP SOCKET 8POS TIN | 3 | 3 | Bulk | A120347-ND | 0.22 | $0.66 | https://www.digikey.com/en/products/detail/te-connectivity-amp-connectors/1-2199298-2/5022039
30 | CR2450 | 1053 | Keystone | BATT HOLDER COIN 24.5MM PC PIN | Bulk | 36-1053-ND | 1.42 | $1.42 | https://www.digikey.com/en/products/detail/keystone-electronics/1053/2745672

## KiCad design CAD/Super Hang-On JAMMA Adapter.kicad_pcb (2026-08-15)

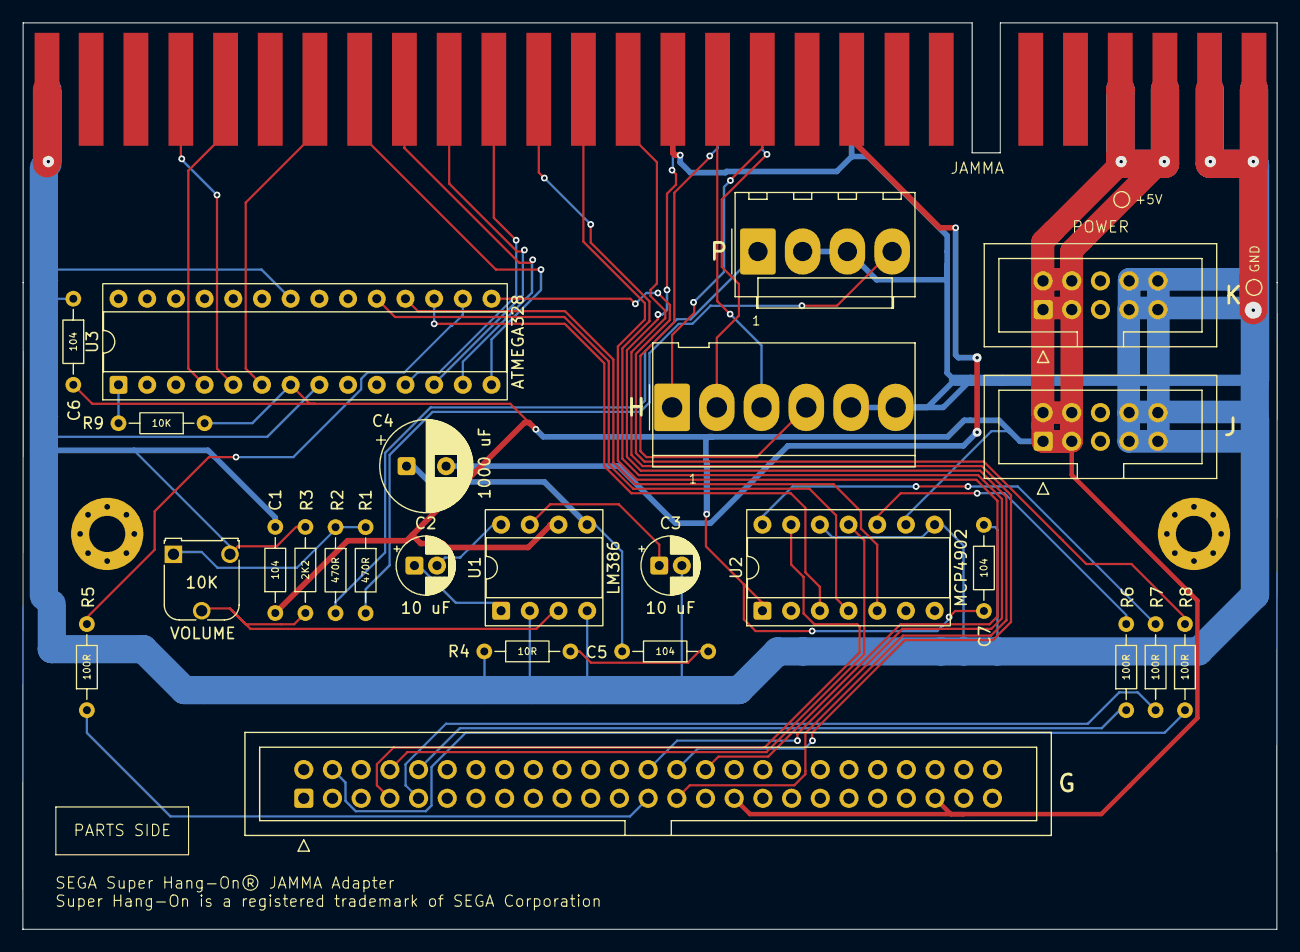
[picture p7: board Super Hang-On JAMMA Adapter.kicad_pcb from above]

Board: 2 copper layers, 111.0 x 80.2 mm, 28 parts (0 on the bottom side), 41 nets.

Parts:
+5V: TestPoint_Pad_D1.0mm
C1, C5, C6, C7: 104; R_Axial_DIN0204_L3.6mm_D1.6mm_P7.62mm_Horizontal
C2, C3: 10 uF; CP_Radial_D5.0mm_P2.00mm
C4: 1000 uF; CP_Radial_D8.0mm_P3.50mm
G: G; IDC-Header_2x25_P2.54mm_Vertical
GND: TestPoint_Pad_D1.0mm
H: H; Molex_KK-396_5273-06A_1x06_P3.96mm_Vertical
J: J; IDC-Header_2x05_P2.54mm_Vertical
JAMMA: HDR_JAMMA_56P_EDGE_CONNECTOR
K: K; IDC-Header_2x05_P2.54mm_Vertical
P: P; Molex_KK-396_A-41791-0004_1x04_P3.96mm_Vertical
R1, R2: 470R; R_Axial_DIN0204_L3.6mm_D1.6mm_P7.62mm_Horizontal
R3: 2K2; R_Axial_DIN0204_L3.6mm_D1.6mm_P7.62mm_Horizontal
R4: 10R; R_Axial_DIN0204_L3.6mm_D1.6mm_P7.62mm_Horizontal
R5, R6, R7, R8: 100R; R_Axial_DIN0204_L3.6mm_D1.6mm_P7.62mm_Horizontal
R9: 10K; R_Axial_DIN0204_L3.6mm_D1.6mm_P7.62mm_Horizontal
U1: LM386; DIP-8_W7.62mm_Socket
U2: MCP4902; DIP-14_W7.62mm_Socket
U3: ATMEGA328; DIP-28_W7.62mm_Socket
VOLUME: 10K; Potentiometer_Runtron_RM-065_Vertical

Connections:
1P_B1: JAMMA.22, U3.6
1P_B3: JAMMA.24, U3.4
1P_B4: JAMMA.25, U3.5
1P_D: JAMMA.19, U3.12
1P_L: JAMMA.20, U3.13
1P_R: JAMMA.21, U3.14
1P_START: G.26, JAMMA.17
1P_U: JAMMA.18, U3.11
+5V: +5V.1, C1.1, C6.2, C7.2, G.31, G.45, J.1, J.2, J.3, J.4, JAMMA.3, JAMMA.4, JAMMA.C, JAMMA.D, K.1, K.2, K.3, K.4, R9.1, U1.6, U2.1, U2.9, U3.7
ACCEL: G.9, R7.1
AUDIO_L: P.1, R2.2
AUDIO_MONO: R1.1, R2.1, VOLUME.1
AUDIO_R: P.4, R1.2
BRK: G.4, R8.1
C5_R4: C5.1, R4.1
COIN_1: G.30, JAMMA.16
GND: C1.2, C3.2, C6.1, C7.1, GND.1, H.5, H.6, J.7, J.8, J.9, J.10, JAMMA.1, JAMMA.2, JAMMA.14, JAMMA.28, JAMMA.A, JAMMA.B, JAMMA.L, JAMMA.f, K.7, K.8, K.9, K.10, P.2, P.3, R3.2, R4.2, U1.2, U1.4, U2.8, U2.12, U3.8, U3.22, VOLUME.3
PB1: R8.2, U3.15
PB2: R5.2, U3.16
PREAMP: R3.1, U1.3, VOLUME.2
PREAMP_OUT: C4.1, C5.2, U1.5
REFA: G.7, U2.13
REFB: G.8, U2.11
SERVICE: G.27, JAMMA.R
SPKR+: C4.2, JAMMA.10
STEER: G.10, R6.1
TEST: G.28, JAMMA.15
TURBO: G.25, R5.1
U1_BYPASS: C3.1, U1.7
U1_GAIN_P1: C2.1, U1.1
U1_GAIN_P8: C2.2, U1.8
U3_MISO_U2_SDI: U2.5, U3.18
U3_MOSI_U2_CS: U2.3, U3.17
U3_RSET: R9.2, U3.1
U3_SCK_U2_SCK: U2.4, U3.19
VID_B: H.3, JAMMA.13
VID_CSYNC: H.4, JAMMA.P
VID_G: H.2, JAMMA.N
VID_R: H.1, JAMMA.12
VOUTA: R7.2, U2.14
VOUTB: R6.2, U2.10

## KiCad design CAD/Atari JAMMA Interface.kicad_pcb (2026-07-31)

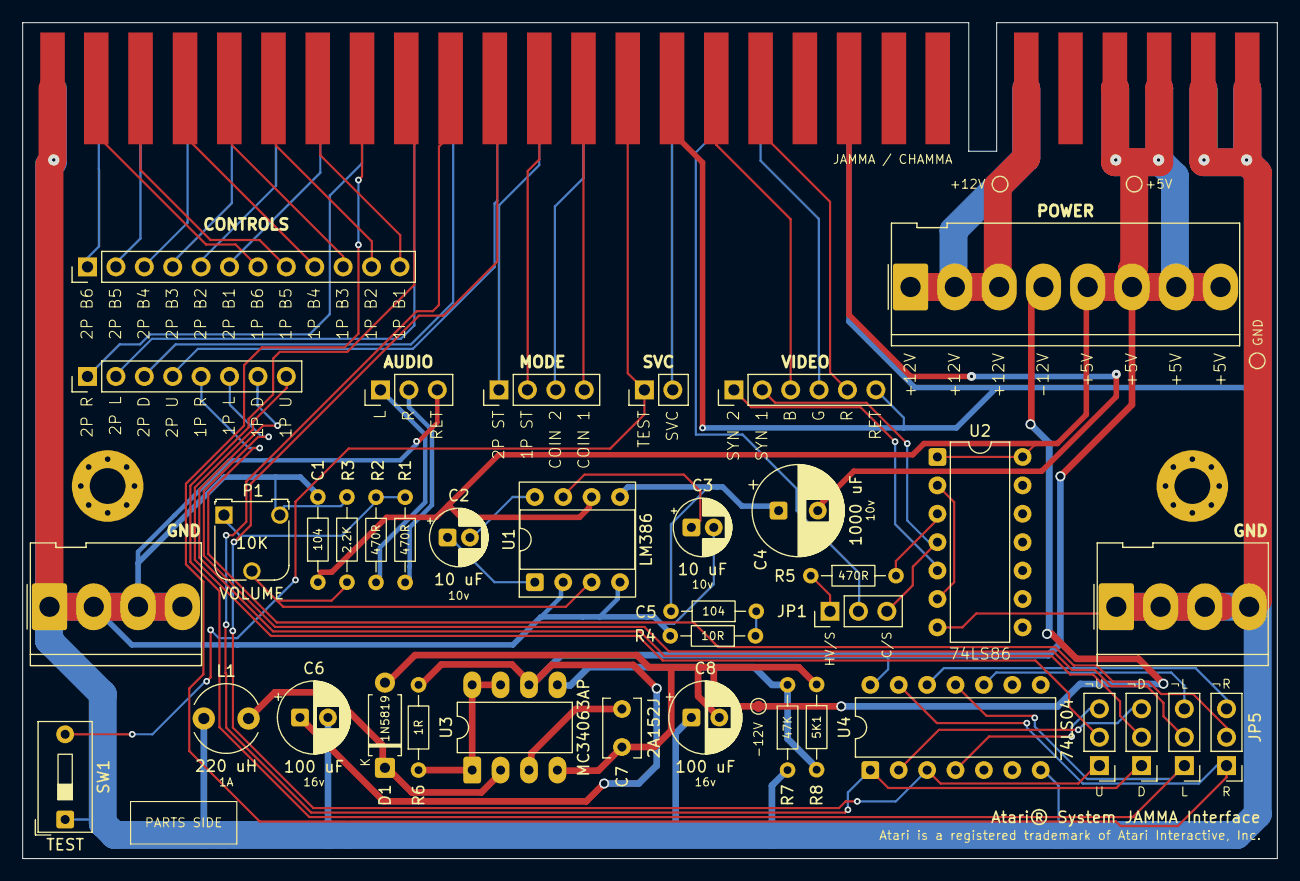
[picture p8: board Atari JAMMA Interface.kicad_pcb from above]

Board: 2 copper layers, 112.2 x 74.8 mm, 43 parts (0 on the bottom side), 61 nets.

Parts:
+5V, +12V: TestPoint_Pad_D1.0mm
-12V: TestPoint_Pad_D1.0mm
AUDIO: PinHeader_1x03_P2.54mm_Vertical
C1, C5: 104; R_Axial_DIN0204_L3.6mm_D1.6mm_P7.62mm_Horizontal
C2, C3: 10 uF; CP_Radial_D5.0mm_P2.00mm
C4: 1000 uF; CP_Radial_D8.0mm_P3.50mm
C6, C8: 100 uF; CP_Radial_D6.3mm_P2.50mm
C7: 2A152J; C_Disc_D5.1mm_W3.2mm_P3.4mm
CONTROLS: PinHeader_1x12_P2.54mm_Vertical
D1: 1N5819; D_A-405_P7.62mm_Horizontal
DIRECTIONALS: PinHeader_1x08_P2.54mm_Vertical
GND: TestPoint_Pad_D1.0mm
GND#2, GND#3: Molex_KK-396_5273-04A_1x04_P3.96mm_Vertical
HV/S: PinHeader_1x03_P2.54mm_Vertical
HV/S#2, HV/S#3, HV/S#4, HV/S#5: PinHeader_1x03_P2.54mm_Vertical
JAMMA / CHAMMA: HDR_JAMMA_56P_EDGE_CONNECTOR
L1: 220 uH; L_Radial_D6.0mm_P4.00mm
MODE: PinHeader_1x04_P2.54mm_Vertical
P1: 10K; Potentiometer_Runtron_RM-065_Vertical
POWER: Molex_KK-396_5273-08A_1x08_P3.96mm_Vertical
R1, R2, R5: 470R; R_Axial_DIN0204_L3.6mm_D1.6mm_P7.62mm_Horizontal
R3: 2.2K; R_Axial_DIN0204_L3.6mm_D1.6mm_P7.62mm_Horizontal
R4: 10R; R_Axial_DIN0204_L3.6mm_D1.6mm_P7.62mm_Horizontal
R6: 1R; R_Axial_DIN0204_L3.6mm_D1.6mm_P7.62mm_Horizontal
R7: 47K; R_Axial_DIN0204_L3.6mm_D1.6mm_P7.62mm_Horizontal
R8: 5K1; R_Axial_DIN0204_L3.6mm_D1.6mm_P7.62mm_Horizontal
SVC: PinHeader_1x02_P2.54mm_Vertical
TEST: SW1; SW_DIP_SPSTx01_Slide_9.78x4.72mm_W7.62mm_P2.54mm
U1: LM386; DIP-8_W7.62mm_Socket
U2: DIP-14_W7.62mm
U3: MC34063AP; DIP-8_W7.62mm_LongPads
U4: 74LS04; DIP-14_W7.62mm
VIDEO: PinHeader_1x06_P2.54mm_Vertical

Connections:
1P_!D: HV/S#5.3, U4.2
1P_!L: HV/S.3, U4.10
1P_!R: HV/S#2.3, U4.12
1P_!U: HV/S#3.3, U4.4
1P_B1: CONTROLS.12, JAMMA / CHAMMA.22
1P_B2: CONTROLS.11, JAMMA / CHAMMA.23
1P_B3: CONTROLS.10, JAMMA / CHAMMA.24
1P_B4: CONTROLS.9, JAMMA / CHAMMA.25
1P_B5: CONTROLS.8, JAMMA / CHAMMA.26
1P_B6: CONTROLS.7, JAMMA / CHAMMA.27
1P_D: HV/S#5.1, JAMMA / CHAMMA.19, U4.1
1P_D_OUT: DIRECTIONALS.7, HV/S#5.2
1P_L: HV/S.1, JAMMA / CHAMMA.20, U4.11
1P_L_OUT: DIRECTIONALS.6, HV/S.2
1P_R: HV/S#2.1, JAMMA / CHAMMA.21, U4.13
1P_R_OUT: DIRECTIONALS.5, HV/S#2.2
1P_START: JAMMA / CHAMMA.17, MODE.2
1P_U: HV/S#3.1, JAMMA / CHAMMA.18, U4.3
1P_U_OUT: DIRECTIONALS.8, HV/S#3.2
2P_B1: CONTROLS.6, JAMMA / CHAMMA.Z
2P_B2: CONTROLS.5, JAMMA / CHAMMA.a
2P_B3: CONTROLS.4, JAMMA / CHAMMA.b
2P_B4: CONTROLS.3, JAMMA / CHAMMA.c
2P_B5: CONTROLS.2, JAMMA / CHAMMA.d
2P_B6: CONTROLS.1, JAMMA / CHAMMA.e
2P_D: DIRECTIONALS.3, JAMMA / CHAMMA.W
2P_L: DIRECTIONALS.2, JAMMA / CHAMMA.X
2P_R: DIRECTIONALS.1, JAMMA / CHAMMA.Y
2P_START: JAMMA / CHAMMA.U, MODE.1
2P_U: DIRECTIONALS.4, JAMMA / CHAMMA.V
+5V: +5V.1, C1.1, C6.1, JAMMA / CHAMMA.3, JAMMA / CHAMMA.4, JAMMA / CHAMMA.C, JAMMA / CHAMMA.D, POWER.5, POWER.6, POWER.7, POWER.8, R6.2, U1.6, U2.1, U2.14, U3.6, U4.14
+12V: +12V.1, JAMMA / CHAMMA.6, JAMMA / CHAMMA.F, POWER.1, POWER.2, POWER.3
-12V: -12V.1, C7.1, C8.2, D1.2, POWER.4, R8.2, U3.4
AUDIO_L: AUDIO.1, R2.2
AUDIO_MONO: P1.1, R1.1, R2.1
AUDIO_R: AUDIO.2, R1.2
C5_R4: C5.1, R4.1
CINV_R10_R9: R7.2, R8.1, U3.5
COIN_1: JAMMA / CHAMMA.16, MODE.4
COIN_2: JAMMA / CHAMMA.T, MODE.3
GND: AUDIO.3, C1.2, C3.2, C6.2, C8.1, GND.1, GND#2.1, GND#2.2, GND#2.3, GND#2.4, GND#3.1, GND#3.2, GND#3.3, GND#3.4, JAMMA / CHAMMA.1, JAMMA / CHAMMA.2, JAMMA / CHAMMA.14, JAMMA / CHAMMA.28, JAMMA / CHAMMA.A, JAMMA / CHAMMA.B, JAMMA / CHAMMA.L, JAMMA / CHAMMA.f, L1.1, P1.3, R3.2, R4.2, R7.1, TEST.1, U1.2, U1.4, U2.7, U4.7, VIDEO.6
PREAMP: P1.2, R3.1, U1.3
PREAMP_OUT: C4.1, C5.2, U1.5
R8: R6.1, U3.1, U3.7, U3.8
SERVICE: JAMMA / CHAMMA.R, SVC.2
SPKR+: C4.2, JAMMA / CHAMMA.10
SWE: D1.1, L1.2, U3.2
TEST: JAMMA / CHAMMA.15, SVC.1, TEST.2
U3_CAP: C7.2, U3.3
U4_BYPASS: C3.1, U1.7
U4_GAIN_P1: C2.1, U1.1
U4_GAIN_P8: C2.2, U1.8
VID_B: JAMMA / CHAMMA.13, VIDEO.3
VID_CSYNC: HV/S#4.2, JAMMA / CHAMMA.P
VID_G: JAMMA / CHAMMA.N, VIDEO.4
VID_NXOR: HV/S#4.1, R5.1
VID_NXOR_R5: R5.2, U2.3
VID_R: JAMMA / CHAMMA.12, VIDEO.5
VID_SYN1: HV/S#4.3, U2.4, VIDEO.2
VID_SYN2: U2.5, VIDEO.1
VID_XOR: U2.2, U2.6

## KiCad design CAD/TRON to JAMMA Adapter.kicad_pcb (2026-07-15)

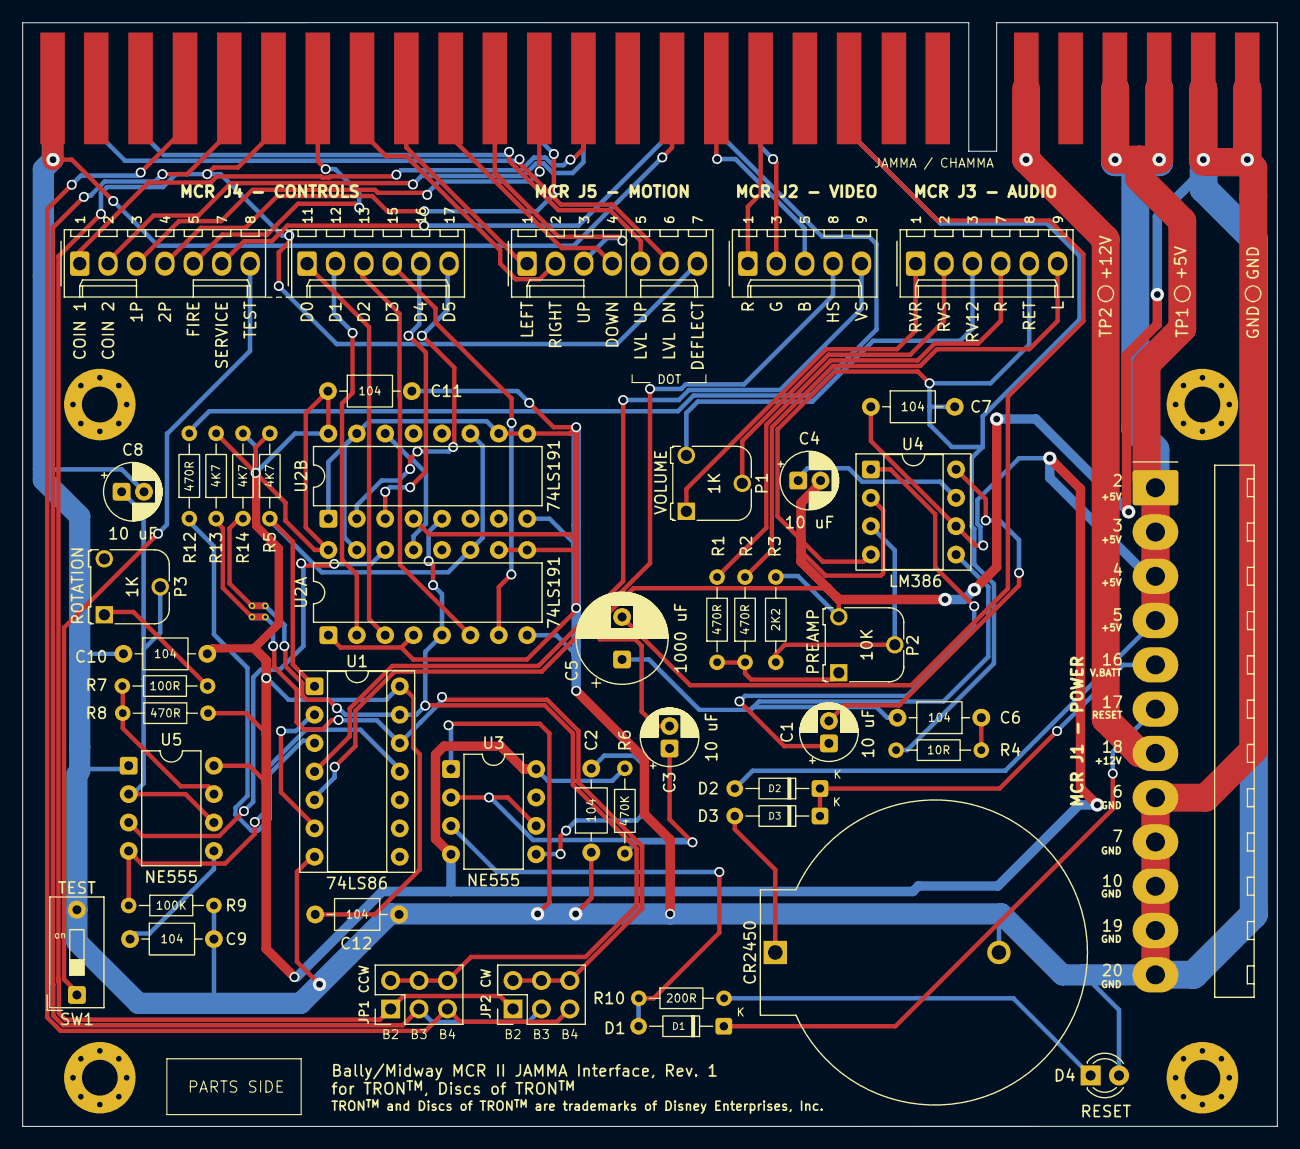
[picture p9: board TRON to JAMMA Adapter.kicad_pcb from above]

Board: 2 copper layers, 112.2 x 98.7 mm, 56 parts (0 on the bottom side), 63 nets.

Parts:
+5V: TP1; TestPoint_Pad_D1.0mm
+12V: TP2; TestPoint_Pad_D1.0mm
C1, C3, C4, C8: 10 uF; CP_Radial_D5.0mm_P2.00mm
C2, C6, C7, C9, C10, C11, C12: 104; C_Axial_L3.8mm_D2.6mm_P7.50mm_Horizontal
C5: 1000 uF; CP_Radial_D8.0mm_P3.80mm
CR2450: BatteryHolder_ComfortableElectronic_CH273-2450_1x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; BatteryHolder_ComfortableElectronic_CH273-2450_1x2450
D1: 1N4148; D_DO-34_SOD68_P7.62mm_Horizontal
D2, D3: 1N5817; D_DO-34_SOD68_P7.62mm_Horizontal
D4: LED; LED_D3.0mm
GND: GND; TestPoint_Pad_D1.0mm
JAMMA / CHAMMA: HDR_JAMMA_56P_EDGE_CONNECTOR
JP1 CCW, JP2 CW: PinHeader_2x03_P2.54mm_Vertical
MCRJ1: Molex_KK-396_A-41792-0012_1x12_P3.96mm_Horizontal
MCRJ2: Molex_KK-254_AE-6410-05A_1x05_P2.54mm_Vertical
MCRJ3, MCRJ4B: Molex_KK-254_AE-6410-06A_1x06_P2.54mm_Vertical
MCRJ4A, MCRJ5: Molex_KK-254_AE-6410-07A_1x07_P2.54mm_Vertical
P1, P3: 1K; Potentiometer_Runtron_RM-065_Vertical
P2: 10K; Potentiometer_Runtron_RM-065_Vertical
PMH1, PMH2, PMH3, PMH4: MountingHole_3.2mm_M3_Pad_Via
R1, R2, R8, R12: 470R; R_Axial_DIN0204_L3.6mm_D1.6mm_P7.62mm_Horizontal
R3: 2K2; R_Axial_DIN0204_L3.6mm_D1.6mm_P7.62mm_Horizontal
R4: 10R; R_Axial_DIN0204_L3.6mm_D1.6mm_P7.62mm_Horizontal
R5, R13, R14: 4K7; R_Axial_DIN0204_L3.6mm_D1.6mm_P7.62mm_Horizontal
R6: 470K; R_Axial_DIN0204_L3.6mm_D1.6mm_P7.62mm_Horizontal
R7: 100R; R_Axial_DIN0204_L3.6mm_D1.6mm_P7.62mm_Horizontal
R9: 100K; R_Axial_DIN0204_L3.6mm_D1.6mm_P7.62mm_Horizontal
R10: 200R; R_Axial_DIN0204_L3.6mm_D1.6mm_P7.62mm_Horizontal
TEST: SW1; SW_DIP_SPSTx01_Slide_9.78x4.72mm_W7.62mm_P2.54mm
U1: 74LS86; DIP-14_W7.62mm_Socket
U2A, U2B: 74LS191; DIP-16_W7.62mm
U3, U5: NE555; DIP-8_W7.62mm
U4: LM386; DIP-8_W7.62mm_Socket

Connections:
1P_B1: JAMMA / CHAMMA.22, MCRJ4A.5
1P_B2: JAMMA / CHAMMA.23, JP1 CCW.1, JP2 CW.1, MCRJ5.7
1P_B3: JAMMA / CHAMMA.24, JP1 CCW.3, JP2 CW.3
1P_B4: JAMMA / CHAMMA.25, JP1 CCW.5, JP2 CW.5
1P_B5: JAMMA / CHAMMA.d, MCRJ5.5
1P_B6: JAMMA / CHAMMA.e, MCRJ5.6
1P_D: JAMMA / CHAMMA.19, MCRJ5.4
1P_L: JAMMA / CHAMMA.20, MCRJ5.1
1P_R: JAMMA / CHAMMA.21, MCRJ5.2
1P_START: JAMMA / CHAMMA.17, MCRJ4A.3
1P_U: JAMMA / CHAMMA.18, MCRJ5.3
2P_START: JAMMA / CHAMMA.U, MCRJ4A.4
+5V: +5V.1, C7.1, C10.2, C11.1, C12.2, D2.2, JAMMA / CHAMMA.3, JAMMA / CHAMMA.4, JAMMA / CHAMMA.C, JAMMA / CHAMMA.D, MCRJ1.1, MCRJ1.2, MCRJ1.3, MCRJ1.4, R5.2, R6.2, R8.2, R13.2, R14.2, U1.14, U2A.16, U2B.16, U3.4, U3.8, U4.6, U5.8
+5V_R5: R5.1, U1.1, U2A.11, U2B.11
+12V_IN: +12V.1, JAMMA / CHAMMA.6, JAMMA / CHAMMA.F, MCRJ1.7
AUDIO_L: MCRJ3.6, R2.2
AUDIO_MONO: P2.1, R1.1, R2.1
AUDIO_OUT: C5.2, JAMMA / CHAMMA.10
AUDIO_PREAMP: P2.2, R3.1, U4.3
AUDIO_PREAMP_OUT: C5.1, C6.2, U4.5
AUDIO_R: MCRJ3.4, R1.2
BATTERY: CR2450.1, D3.2
C6_R4: C6.1, R4.1
CCW_IN: JP1 CCW.2, JP1 CCW.4, JP1 CCW.6, U1.13, U2A.5, U2B.5
CLK: U2A.14, U5.3
CLK_GATE: R9.1, U1.11, U5.4
COIN_1: JAMMA / CHAMMA.16, MCRJ4A.1
COIN_2: JAMMA / CHAMMA.T, MCRJ4A.2
CW_IN: JP2 CW.2, JP2 CW.4, JP2 CW.6, U1.12
E1: MCRJ4B.1, U2A.3
E2: MCRJ4B.2, U2A.2
E3: MCRJ4B.3, U2A.6
E4: MCRJ4B.4, U2A.7
E5: MCRJ4B.5, U2B.3
E6: MCRJ4B.6, U2B.2
GND: C2.1, C3.2, C4.2, C7.2, C8.2, C9.2, C10.1, C11.2, C12.1, CR2450.2, D4.2, GND.1, JAMMA / CHAMMA.1, JAMMA / CHAMMA.2, JAMMA / CHAMMA.14, JAMMA / CHAMMA.28, JAMMA / CHAMMA.A, JAMMA / CHAMMA.B, JAMMA / CHAMMA.L, JAMMA / CHAMMA.f, MCRJ1.8, MCRJ1.9, MCRJ1.10, MCRJ1.11, MCRJ1.12, MCRJ3.5, P2.3, R3.2, R4.2, R9.2, TEST.2, U1.7, U2A.1, U2A.4, U2A.8, U2A.9, U2A.10, U2A.15, U2B.1, U2B.4, U2B.8, U2B.9, U2B.10, U2B.15, U3.1, U4.2, U4.4, U5.1
R6_U3_P2_P6: C3.1, R6.1, U3.2, U3.6
RESET_5V: D1.2, R10.1, U3.3
RESET_5V_OUT: D1.1, MCRJ1.6
RESET_LED: D4.1, R10.2
SERVICE_SW: JAMMA / CHAMMA.R, MCRJ4A.6
TEST_SW: MCRJ4A.7, TEST.1
U1_P6_U1_P2: U1.2, U1.6
U3_CTRL: C2.2, U3.5
U4_BYPASS: C4.1, U4.7
U4_GAIN_P1: C1.1, U4.1
U4_GAIN_P8: C1.2, U4.8
U5_CTRL: C9.1, U5.5
U5_DIS: R7.1, R8.1, U5.7
U5_DIS_R2: P3.1, R7.2
U5_TRIG: C8.1, P3.2, U5.2, U5.6
U6_RCO: U2A.13, U2B.14
V.BATT: D2.1, D3.1, MCRJ1.5
VIDEO_B: JAMMA / CHAMMA.13, MCRJ2.3
VIDEO_G: JAMMA / CHAMMA.N, MCRJ2.2
VIDEO_HSYNC: MCRJ2.4, U1.5
VIDEO_RED: JAMMA / CHAMMA.12, MCRJ2.1
VIDEO_SYNC: JAMMA / CHAMMA.P, R12.2
VIDEO_SYNC_R12: R12.1, U1.3
VIDEO_VSYNC: MCRJ2.5, U1.4
VOL_GND: MCRJ3.3, P1.3
VOL_IN: MCRJ3.1, P1.1
VOL_OUT: MCRJ3.2, P1.2

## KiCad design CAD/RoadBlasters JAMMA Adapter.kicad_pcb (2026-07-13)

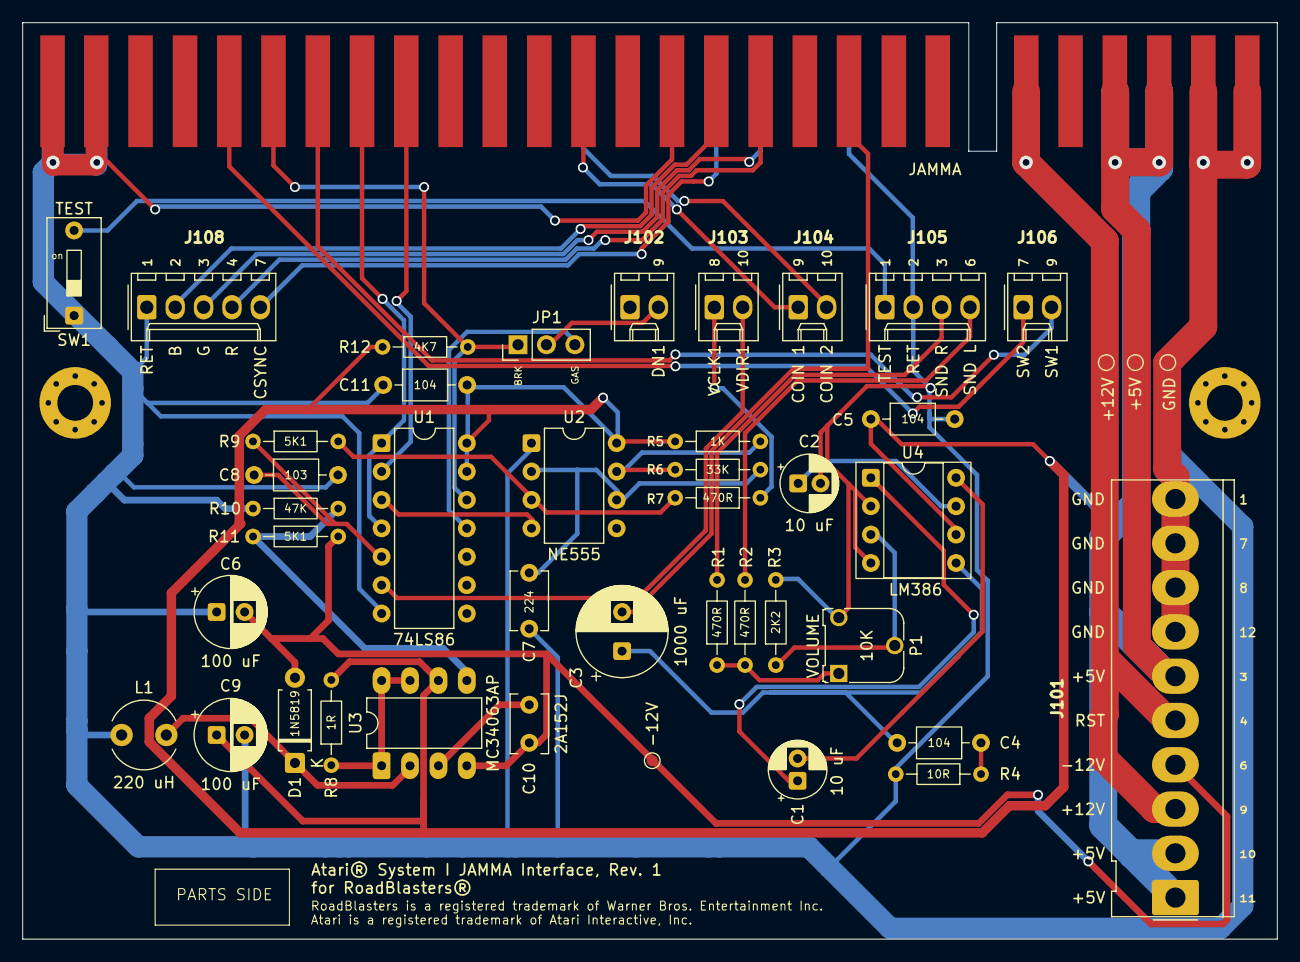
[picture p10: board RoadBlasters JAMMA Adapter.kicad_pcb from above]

Board: 2 copper layers, 112.2 x 82.0 mm, 46 parts (0 on the bottom side), 39 nets.

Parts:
+5V: TP2; TestPoint_Pad_D1.0mm
+12V: TP3; TestPoint_Pad_D1.0mm
-12V: TP4; TestPoint_Pad_D1.0mm
C1, C2: 10 uF; CP_Radial_D5.0mm_P2.00mm
C3: 1000 uF; CP_Radial_D8.0mm_P3.50mm
C4, C5, C11: 104; C_Axial_L3.8mm_D2.6mm_P7.50mm_Horizontal
C6, C9: 100 uF; CP_Radial_D6.3mm_P2.50mm
C7: 224; C_Disc_D5.1mm_W3.2mm_P5.00mm
C8: 103; C_Axial_L3.8mm_D2.6mm_P7.50mm_Horizontal
C10: 2A152J; C_Disc_D5.1mm_W3.2mm_P3.4mm
D1: 1N5819; D_A-405_P7.62mm_Horizontal
GND: TP1; TestPoint_Pad_D1.0mm
J101: Molex_KK-396_5273-10A_1x10_P3.96mm_Vertical
J102, J103, J104, J106: Molex_KK-254_AE-6410-02A_1x02_P2.54mm_Vertical
J105: Molex_KK-254_AE-6410-04A_1x04_P2.54mm_Vertical
J108: Molex_KK-254_AE-6410-05A_1x05_P2.54mm_Vertical
JAMMA: HDR_JAMMA_56P_EDGE_CONNECTOR
JP1: PinHeader_1x03_P2.54mm_Vertical
L1: 220 uH; L_Radial_D6.0mm_P4.00mm
P1: 10K; Potentiometer_Runtron_RM-065_Vertical
PMH1, PMH4: MountingHole_3.2mm_M3_Pad_Via
R1: R1; R_Axial_DIN0204_L3.6mm_D1.6mm_P7.62mm_Horizontal
R2, R7: 470R; R_Axial_DIN0204_L3.6mm_D1.6mm_P7.62mm_Horizontal
R3: 2K2; R_Axial_DIN0204_L3.6mm_D1.6mm_P7.62mm_Horizontal
R4: R_Axial_DIN0204_L3.6mm_D1.6mm_P7.62mm_Horizontal
R5: 1K; R_Axial_DIN0204_L3.6mm_D1.6mm_P7.62mm_Horizontal
R6: 33K; R_Axial_DIN0204_L3.6mm_D1.6mm_P7.62mm_Horizontal
R8: 1R; R_Axial_DIN0204_L3.6mm_D1.6mm_P7.62mm_Horizontal
R9, R11: 5K1; R_Axial_DIN0204_L3.6mm_D1.6mm_P7.62mm_Horizontal
R10: 47K; R_Axial_DIN0204_L3.6mm_D1.6mm_P7.62mm_Horizontal
R12: 4K7; R_Axial_DIN0204_L3.6mm_D1.6mm_P7.62mm_Horizontal
TEST: SW1; SW_DIP_SPSTx01_Slide_9.78x4.72mm_W7.62mm_P2.54mm
U1: 74LS86; DIP-14_W7.62mm
U2: NE555; DIP-8_W7.62mm
U3: MC34063AP; DIP-8_W7.62mm_LongPads
U4: LM386; DIP-8_W7.62mm_Socket

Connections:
1P_B1: J106.2, JAMMA.22
1P_B2: JAMMA.23, JP1.1, R12.2, U1.12
1P_B2_OUT: J102.2, JP1.2
1P_B3: J106.1, JAMMA.24
1P_L: JAMMA.20, U1.2
1P_R: JAMMA.21, U1.1, U1.4
!1P_B2: JP1.3, U1.11
+5V: +5V.1, C5.1, C9.1, C11.2, J101.1, J101.2, J101.6, JAMMA.3, JAMMA.4, JAMMA.C, JAMMA.D, R5.1, R8.2, R12.1, U1.13, U1.14, U2.8, U3.6, U4.6
+12V: +12V.1, J101.3, J101.5, JAMMA.6, JAMMA.F
-12V: -12V.1, C6.2, C10.1, D1.2, J101.4, R11.2, U3.4
AUDIO_L: J105.4, R2.2
AUDIO_MONO: P1.1, R1.1, R2.1
AUDIO_OUT: C3.2, JAMMA.10
AUDIO_PREAMP: P1.2, R3.1, U4.3
AUDIO_PREAMP_OUT: C3.1, C4.2, U4.5
AUDIO_R: J105.3, R1.2
C4_R4: C4.1, R4.1
CINV_R10_R9: R10.2, R11.1, U3.5
COIN_1: J104.1, JAMMA.16
COIN_2: J104.2, JAMMA.T
GND: C2.2, C5.2, C6.1, C7.1, C8.2, C9.2, C11.1, GND.1, J101.7, J101.8, J101.9, J101.10, J105.2, J108.1, JAMMA.1, JAMMA.2, JAMMA.14, JAMMA.27, JAMMA.28, JAMMA.A, JAMMA.B, JAMMA.L, JAMMA.e, JAMMA.f, L1.1, P1.3, R3.2, R4.2, R10.1, TEST.1, U1.7, U2.1, U4.2, U4.4
R8: R8.1, U3.1, U3.7, U3.8
SWE: D1.1, L1.2, U3.2
TEST_SW: J105.1, TEST.2
U2_DIS: R5.2, R6.1, U2.7
U2_RESET: U1.3, U2.4
U2_THR: C7.2, R6.2, U2.2, U2.6
U3_CAP: C10.2, U3.3
U4_BYPASS: C2.1, U4.7
U4_GAIN_P1: C1.1, U4.1
U4_GAIN_P8: C1.2, U4.8
VCLK1: R7.2, R9.2, U2.3
VCLK1_DELAYED: C8.1, R9.1, U1.5
VCLK1_OUT: J103.1, R7.1
VDIR1_OUT: J103.2, U1.6
VIDEO_B: J108.2, JAMMA.13
VIDEO_G: J108.3, JAMMA.N
VIDEO_R: J108.4, JAMMA.12
VIDEO_SYNC: J108.5, JAMMA.P

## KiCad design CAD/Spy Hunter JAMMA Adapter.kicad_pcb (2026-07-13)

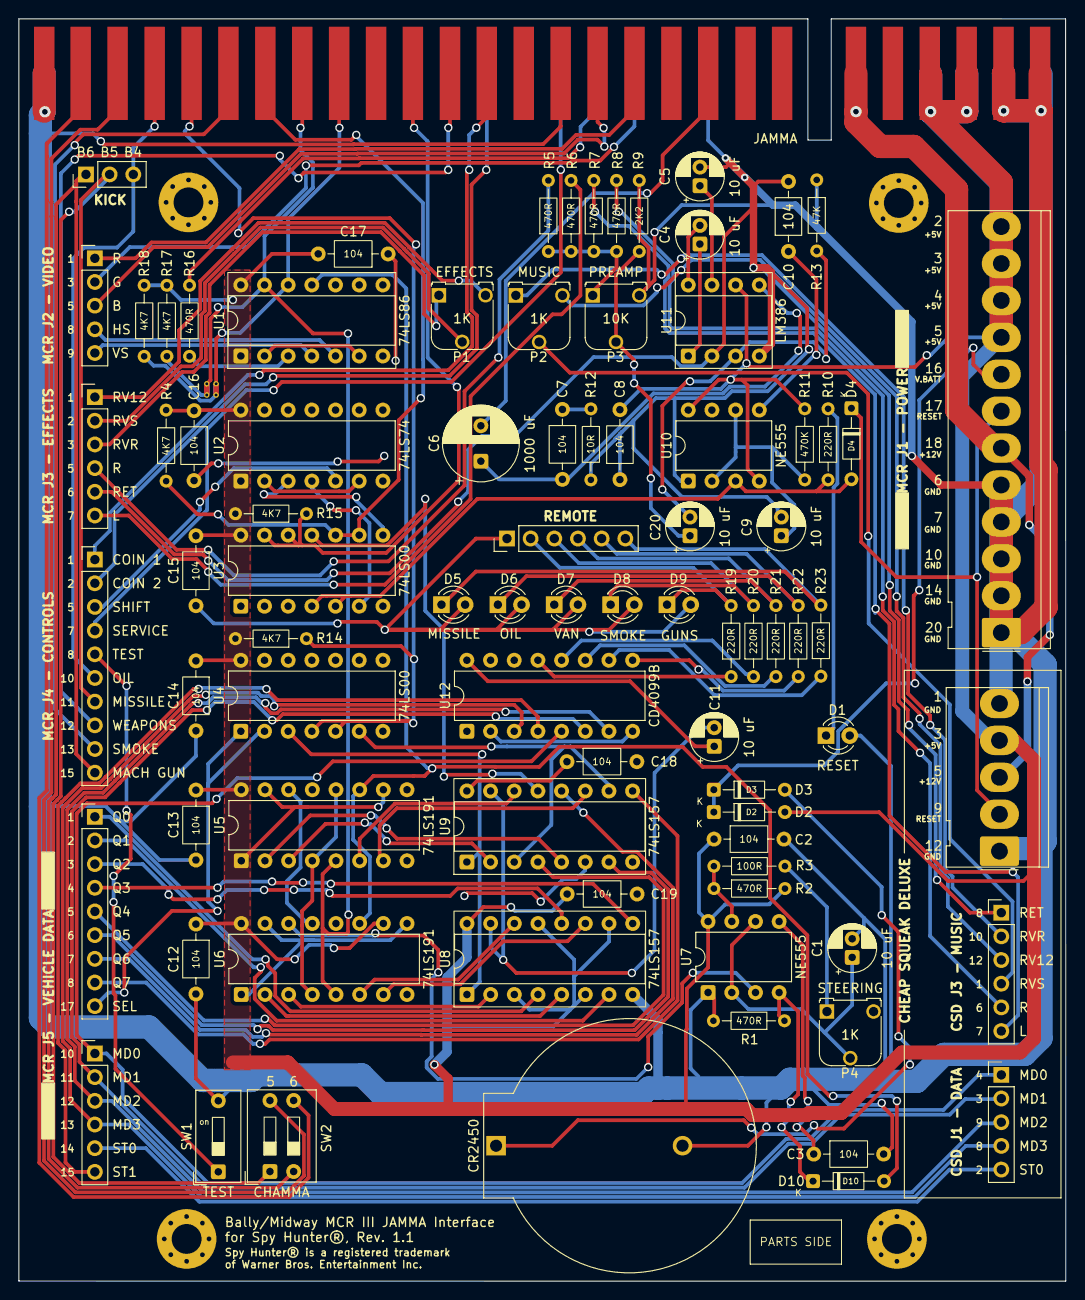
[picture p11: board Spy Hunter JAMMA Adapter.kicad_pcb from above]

Board: 2 copper layers, 112.3 x 135.4 mm, 88 parts (0 on the bottom side), 102 nets.

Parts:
C1, C4, C5, C9, C11, C20: 10 uF; CP_Radial_D5.0mm_P2.00mm
C2, C3, C7, C8, C10, C12, C13, C14, C15, C16, C17, C18, C19: 104; C_Axial_L3.8mm_D2.6mm_P7.50mm_Horizontal
C6: 1000 uF; CP_Radial_D8.0mm_P3.80mm
CR2450: BatteryHolder_ComfortableElectronic_CH273-2450_1x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; BatteryHolder_ComfortableElectronic_CH273-2450_1x2450
CSDJ1: PinHeader_1x05_P2.54mm_Vertical
CSDJ2: Molex_KK-396_5273-05A_1x05_P3.96mm_Vertical
CSDJ3: PinHeader_1x06_P2.54mm_Vertical
D1, D5, D6, D7, D8, D9: LED; LED_D3.0mm
D2, D3: 1N5817; D_DO-34_SOD68_P7.62mm_Horizontal
D4, D10: 1N4148; D_DO-34_SOD68_P7.62mm_Horizontal
JAMMA: HDR_JAMMA_56P_EDGE_CONNECTOR
KICK: PinHeader_1x03_P2.54mm_Vertical
MCR J5 - LAMPS: PinHeader_1x06_P2.54mm_Vertical
MCRJ1: Molex_KK-396_5273-12A_1x12_P3.96mm_Vertical
MCRJ2: PinHeader_1x05_P2.54mm_Vertical
MCRJ3: PinHeader_1x06_P2.54mm_Vertical
MCRJ4: PinHeader_1x10_P2.54mm_Vertical
MCRJ5: PinHeader_1x09_P2.54mm_Vertical
P1, P2, P4: 1K; Potentiometer_Runtron_RM-065_Vertical
P3: 10K; Potentiometer_Runtron_RM-065_Vertical
PMH1, PMH2, PMH3, PMH4: MountingHole_3.2mm_M3_Pad_Via
R1, R2, R5, R6, R7, R8, R16: 470R; R_Axial_DIN0204_L3.6mm_D1.6mm_P7.62mm_Horizontal
R3: 100R; R_Axial_DIN0204_L3.6mm_D1.6mm_P7.62mm_Horizontal
R4, R14, R15, R17, R18: 4K7; R_Axial_DIN0204_L3.6mm_D1.6mm_P7.62mm_Horizontal
R9: 2K2; R_Axial_DIN0204_L3.6mm_D1.6mm_P7.62mm_Horizontal
R10, R19, R20, R21, R22, R23: 220R; R_Axial_DIN0204_L3.6mm_D1.6mm_P7.62mm_Horizontal
R11: 470K; R_Axial_DIN0204_L3.6mm_D1.6mm_P7.62mm_Horizontal
R12: 10R; R_Axial_DIN0204_L3.6mm_D1.6mm_P7.62mm_Horizontal
R13: 47K; R_Axial_DIN0204_L3.6mm_D1.6mm_P7.62mm_Horizontal
REMOTE: PinHeader_1x06_P2.54mm_Vertical
SW2: SW_DIP_SPSTx02_Slide_9.78x7.26mm_W7.62mm_P2.54mm
TEST: SW1; SW_DIP_SPSTx01_Slide_9.78x4.72mm_W7.62mm_P2.54mm
U1: 74LS86; DIP-14_W7.62mm_Socket
U2: 74LS74; DIP-14_W7.62mm
U3, U4: 74LS00; DIP-14_W7.62mm
U5, U6: 74LS191; DIP-16_W7.62mm
U7, U10: NE555; DIP-8_W7.62mm
U8, U9: 74LS157; DIP-16_W7.62mm_Socket
U11: LM386; DIP-8_W7.62mm_Socket
U12: CD4099B; DIP-16_W7.62mm

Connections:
1P_B1: JAMMA.22, R4.1, U3.9, U3.10
1P_B2: JAMMA.23, MCRJ4.9
1P_B3: JAMMA.24, R14.1, U4.4, U4.5
1P_B4: JAMMA.25, KICK.3, MCRJ4.6
1P_B5: KICK.2, MCRJ4.7, SW2.1
1P_B5_CHAMMA: JAMMA.26, SW2.4
1P_B6: KICK.1, MCRJ4.10, SW2.2
1P_B6_CHAMMA: JAMMA.27, SW2.3
1P_GAS: U4.6, U9.3, U9.10
1P_LEFT: JAMMA.20, U1.12
1P_RIGHT: JAMMA.21, U1.13, U5.5, U6.5
1P_START: JAMMA.17, MCRJ4.8
1P_TURBO: U3.11, U9.13
1P_U: JAMMA.18, R15.1, U3.12, U3.13
!RST: U2.4, U3.6
!SEL: U4.3, U8.1, U9.1
!SHIFT_LATCH: U2.2, U2.6
+5V: C2.1, C8.2, C11.1, C12.1, C13.1, C14.1, C15.1, C16.1, C17.2, C18.1, C19.1, CSDJ2.4, D2.2, JAMMA.3, JAMMA.4, JAMMA.C, JAMMA.D, MCRJ1.9, MCRJ1.10, MCRJ1.11, MCRJ1.12, R2.2, R4.2, R11.2, R14.2, R15.2, R17.2, R18.2, U1.1, U1.14, U2.1, U2.14, U3.14, U4.14, U5.1, U5.10, U5.15, U5.16, U6.10, U6.16, U7.8, U8.3, U8.6, U8.10, U8.13, U8.16, U9.6, U9.16, U10.4, U10.8, U11.6, U12.16
+5V_RST: CSDJ2.2, D4.1, MCRJ1.7
+12V: CSDJ2.3, JAMMA.6, JAMMA.F, MCRJ1.6
AUDIO_MONO: P3.1, R5.1, R6.1, R7.1, R8.1
AUDIO_OUT: C6.2, JAMMA.10
AUDIO_PREAMP: C20.1, P3.2, R9.1
AUDIO_PREAMP_COUPLED: C20.2, R13.2, U11.3
AUDIO_PREAMP_OUT: C6.1, C7.2, U11.5
BATT+: CR2450.1, D3.2
C7_R12: C7.1, R12.1
CLK: U6.14, U7.3
CLK_GATE: D10.2, U1.11, U5.11, U6.11
COIN_1: JAMMA.16, MCRJ4.1
COIN_2: JAMMA.T, MCRJ4.2
D5: D5.1, R23.2, REMOTE.6
D6: D6.1, R22.2, REMOTE.5
D7: D7.1, R21.2, REMOTE.4
D8: D8.1, R20.2, REMOTE.3
D9: D9.1, R19.2, REMOTE.2
EFFECTS_L: MCRJ3.6, R6.2
EFFECTS_R: MCRJ3.4, R5.2
EFFECTS_RV12: MCRJ3.1, P1.3
EFFECTS_RVR: MCRJ3.3, P1.1
EFFECTS_RVS: MCRJ3.2, P1.2
GND: C1.2, C2.2, C3.2, C5.2, C8.1, C9.2, C10.2, C11.2, C12.2, C13.2, C14.2, C15.2, C16.2, C17.1, C18.2, C19.2, CR2450.2, CSDJ2.1, CSDJ2.5, CSDJ3.1, D1.2, D5.2, D6.2, D7.2, D8.2, D9.2, JAMMA.1, JAMMA.2, JAMMA.14, JAMMA.28, JAMMA.A, JAMMA.B, JAMMA.L, JAMMA.f, MCRJ1.1, MCRJ1.2, MCRJ1.3, MCRJ1.4, MCRJ1.5, MCRJ3.5, P3.3, R1.2, R9.2, R12.2, R13.1, REMOTE.1, TEST.2, U1.7, U2.7, U3.7, U4.7, U5.8, U5.9, U6.1, U6.8, U6.9, U6.15, U7.1, U8.8, U8.15, U9.8, U9.15, U10.1, U11.2, U11.4, U12.2, U12.8
J5_ST0: CSDJ1.5, MCR J5 - LAMPS.5
MAXMIN_CTEN: U5.4, U5.12, U6.4
MUSIC_L: CSDJ3.6, R7.2
MUSIC_R: CSDJ3.5, R8.2
MUSIC_RV12: CSDJ3.3, P2.3
MUSIC_RVR: CSDJ3.2, P2.1
MUSIC_RVS: CSDJ3.4, P2.2
Q0: MCRJ5.1, U8.4
Q1: MCRJ5.2, U8.7
Q2: MCRJ5.3, U8.12
Q3: MCRJ5.4, U8.9
Q4: MCRJ5.5, U9.4
Q5: MCRJ5.6, U9.7
Q6: MCRJ5.7, U9.12
Q7: MCRJ5.8, U9.9
RST: D4.2, R10.1, U3.4, U3.5, U10.3
RST_LED: D1.1, R10.2
SEL: MCRJ5.9, U4.1, U4.2
SERVICE_SW: JAMMA.R, MCRJ4.4
SHIFT_LATCH: MCRJ4.3, U2.5
TEST_SW: MCRJ4.5, TEST.1
U2_CLK: U2.3, U3.8
U6_RCO: U5.14, U6.13
U7_CTL: C3.1, U7.5
U7_DIS: R2.1, R3.1, U7.7
U7_DIS_P4_1: P4.1, R3.2
U7_RESET: D10.1, R1.1, U7.4
U7_TRIG: C1.1, P4.2, U7.2, U7.6
U8_I0a: U6.3, U8.2
U8_I0b: U6.2, U8.5
U8_I0c: U6.6, U8.14
U8_I0d: U6.7, U8.11
U9_I0a: U5.3, U9.2
U9_I0b: U5.2, U9.5
U9_I0c: U5.6, U9.14
U9_I0d: U5.7, U9.11
U10_CTL: C10.1, U10.5
U10_TRIG: C9.1, R11.1, U10.2, U10.6
U11_BYPASS: C5.1, U11.7
U11_GAIN_P1: C4.1, U11.1
U11_GAIN_P8: C4.2, U11.8
U12_A0: CSDJ1.1, MCR J5 - LAMPS.1, U12.5
U12_A1: CSDJ1.2, MCR J5 - LAMPS.2, U12.6
U12_A2: CSDJ1.3, MCR J5 - LAMPS.3, U12.7
U12_DATA: CSDJ1.4, MCR J5 - LAMPS.4, U12.3
U12_DISABLE: MCR J5 - LAMPS.6, U12.4
U12_Q0: R22.1, U12.9
U12_Q1: R23.1, U12.10
U12_Q2: R21.1, U12.11
U12_Q3: R20.1, U12.12
U12_Q4: R19.1, U12.13
V.BATT: D2.1, D3.1, MCRJ1.8
VIDEO_B: JAMMA.13, MCRJ2.3
VIDEO_G: JAMMA.N, MCRJ2.2
VIDEO_HSYNC: MCRJ2.4, U1.5
VIDEO_NXOR: R16.1, U1.3
VIDEO_R: JAMMA.12, MCRJ2.1
VIDEO_SYNC_OUT: JAMMA.P, R16.2
VIDEO_VSYNC: MCRJ2.5, U1.4
VIDEO_XOR: U1.2, U1.6

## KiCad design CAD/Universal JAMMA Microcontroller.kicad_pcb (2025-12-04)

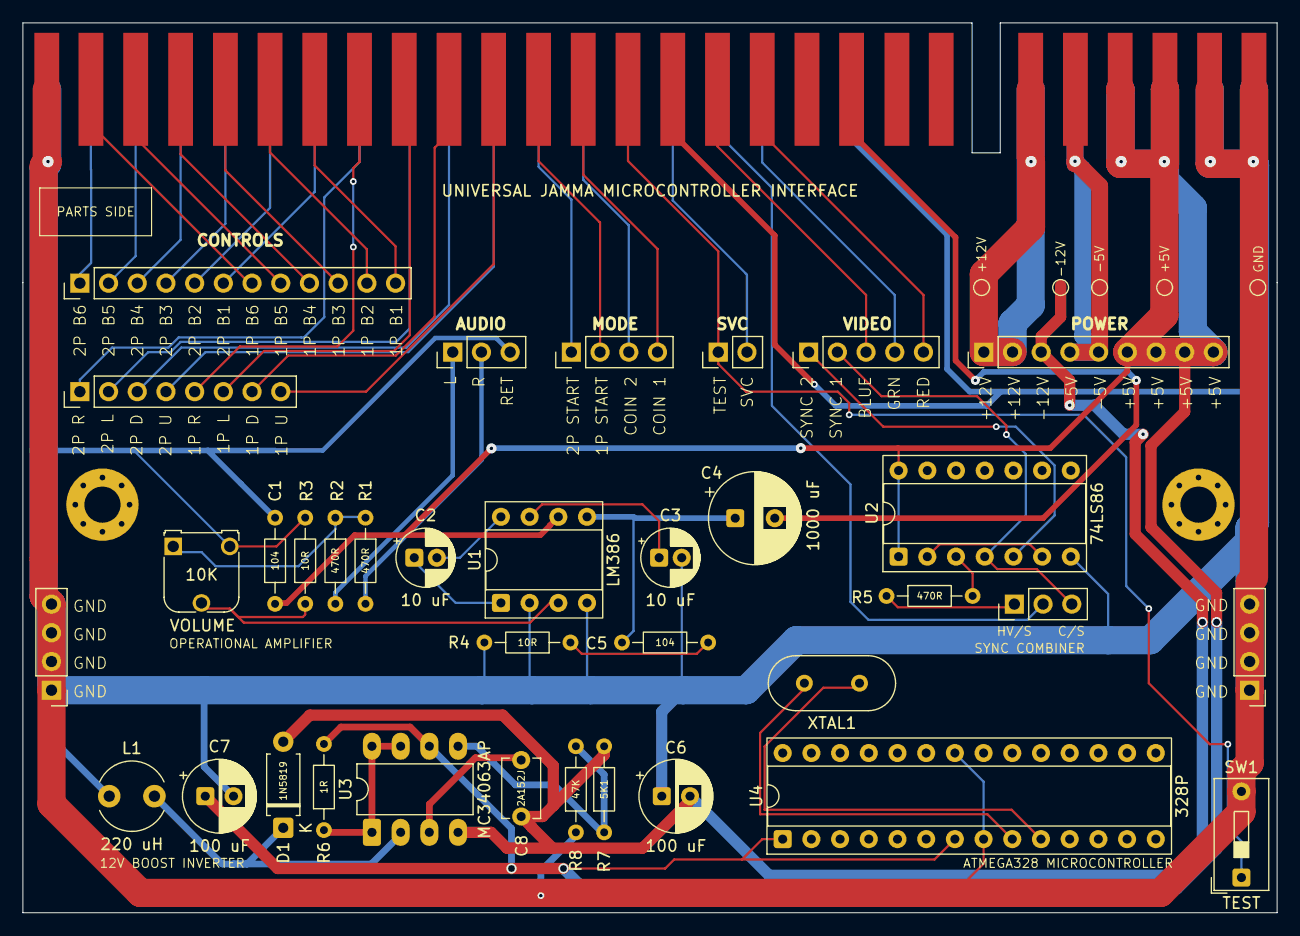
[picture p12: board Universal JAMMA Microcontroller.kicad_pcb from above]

Board: 2 copper layers, 111.0 x 78.8 mm, 41 parts (0 on the bottom side), 56 nets.

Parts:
+5V, +12V: TestPoint_Pad_D1.0mm
-5V, -12V: TestPoint_Pad_D1.0mm
AUDIO: PinHeader_1x03_P2.54mm_Vertical
C1, C5: 104; R_Axial_DIN0204_L3.6mm_D1.6mm_P7.62mm_Horizontal
C2, C3: 10 uF; CP_Radial_D5.0mm_P2.00mm
C4: 1000 uF; CP_Radial_D8.0mm_P3.50mm
C6, C7: 100 uF; CP_Radial_D6.3mm_P2.50mm
C8: 2A152J; C_Disc_D5.1mm_W3.2mm_P5.00mm
CONTROLS: PinHeader_1x12_P2.54mm_Vertical
D1: 1N5819; D_A-405_P7.62mm_Horizontal
DIRECTIONALS: PinHeader_1x08_P2.54mm_Vertical
GND: TestPoint_Pad_D1.0mm
Ground: PinHeader_1x04_P2.54mm_Vertical
Ground#2: PinHeader_1x04_P2.54mm_Vertical
HV/S: PinHeader_1x03_P2.54mm_Vertical
JAMMA: HDR_JAMMA_56P_EDGE_CONNECTOR
L1: 220 uH; L_Radial_D6.0mm_P4.00mm
MODE: PinHeader_1x04_P2.54mm_Vertical
POWER: PinHeader_1x09_P2.54mm_Vertical
R1, R2, R5: 470R; R_Axial_DIN0204_L3.6mm_D1.6mm_P7.62mm_Horizontal
R3, R4: 10R; R_Axial_DIN0204_L3.6mm_D1.6mm_P7.62mm_Horizontal
R6: 1R; R_Axial_DIN0204_L3.6mm_D1.6mm_P7.62mm_Horizontal
R7: 5K1; R_Axial_DIN0204_L3.6mm_D1.6mm_P7.62mm_Horizontal
R8: 47K; R_Axial_DIN0204_L3.6mm_D1.6mm_P7.62mm_Horizontal
SVC: PinHeader_1x02_P2.54mm_Vertical
TEST: SW1; SW_DIP_SPSTx01_Slide_9.78x4.72mm_W7.62mm_P2.54mm
U1: LM386; DIP-8_W7.62mm_Socket
U2: 74LS86; DIP-14_W7.62mm_Socket
U3: MC34063AP; DIP-8_W7.62mm_LongPads
U4: 328P; DIP-28_W7.62mm_Socket
VIDEO: PinHeader_1x05_P2.54mm_Vertical
VOLUME: 10K; Potentiometer_Runtron_RM-065_Vertical
XTAL1: Crystal_HC49-4H_Vertical

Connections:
1P_B1: CONTROLS.12, JAMMA.22
1P_B2: CONTROLS.11, JAMMA.23
1P_B3: CONTROLS.10, JAMMA.24
1P_B4: CONTROLS.9, JAMMA.25
1P_B5: CONTROLS.8, JAMMA.26
1P_B6: CONTROLS.7, JAMMA.27
1P_D: DIRECTIONALS.7, JAMMA.19
1P_L: DIRECTIONALS.6, JAMMA.20
1P_R: DIRECTIONALS.5, JAMMA.21
1P_START: JAMMA.17, MODE.2
1P_U: DIRECTIONALS.8, JAMMA.18
2P_B1: CONTROLS.6, JAMMA.Z
2P_B2: CONTROLS.5, JAMMA.a
2P_B3: CONTROLS.4, JAMMA.b
2P_B4: CONTROLS.3, JAMMA.c
2P_B5: CONTROLS.2, JAMMA.d
2P_B6: CONTROLS.1, JAMMA.e
2P_D: DIRECTIONALS.3, JAMMA.W
2P_L: DIRECTIONALS.2, JAMMA.X
2P_R: DIRECTIONALS.1, JAMMA.Y
2P_START: JAMMA.U, MODE.1
2P_U: DIRECTIONALS.4, JAMMA.V
+5V: +5V.1, C1.1, C7.1, JAMMA.3, JAMMA.4, JAMMA.C, JAMMA.D, POWER.6, POWER.7, POWER.8, POWER.9, R6.2, U1.6, U2.1, U2.14, U3.6, U4.1, U4.7
+12V: +12V.1, JAMMA.6, JAMMA.F, POWER.1, POWER.2
-5V: -5V.1, JAMMA.5, JAMMA.E, POWER.4, POWER.5
-12V: -12V.1, C6.2, C8.1, D1.2, POWER.3, R7.2, U3.4
AUDIO_L: AUDIO.1, R2.2
AUDIO_MONO: R1.1, R2.1, VOLUME.1
AUDIO_R: AUDIO.2, R1.2
C5_R4: C5.1, R4.1
CINV_R7_R8: R7.1, R8.2, U3.5
COIN_1: JAMMA.16, MODE.4
COIN_2: JAMMA.T, MODE.3
GND: AUDIO.3, C1.2, C3.2, C6.1, C7.2, GND.1, Ground.1, Ground.2, Ground.3, Ground.4, Ground#2.1, Ground#2.2, Ground#2.3, Ground#2.4, JAMMA.1, JAMMA.2, JAMMA.14, JAMMA.28, JAMMA.A, JAMMA.B, JAMMA.L, JAMMA.f, L1.1, R3.2, R4.2, R8.1, TEST.2, U1.2, U1.4, U2.7, U4.8, U4.22, VOLUME.3
PB6: U4.9, XTAL1.2
PB7: U4.10, XTAL1.1
PREAMP: R3.1, U1.3, VOLUME.2
PREAMP_OUT: C4.1, C5.2, U1.5
R6: R6.1, U3.1, U3.7, U3.8
SERVICE: JAMMA.R, SVC.2
SPKR+: C4.2, JAMMA.10
SWE: D1.1, L1.2, U3.2
TEST: JAMMA.15, SVC.1, TEST.1
U3_CAP: C8.2, U3.3
U4_BYPASS: C3.1, U1.7
U4_GAIN_P1: C2.1, U1.1
U4_GAIN_P8: C2.2, U1.8
VID_B: JAMMA.13, VIDEO.3
VID_CSYNC: HV/S.2, JAMMA.P
VID_G: JAMMA.N, VIDEO.4
VID_NXOR: HV/S.1, R5.1
VID_NXOR_R5: R5.2, U2.3
VID_R: JAMMA.12, VIDEO.5
VID_SYN1: HV/S.3, U2.4, VIDEO.2
VID_SYN2: U2.5, VIDEO.1
VID_XOR: U2.2, U2.6

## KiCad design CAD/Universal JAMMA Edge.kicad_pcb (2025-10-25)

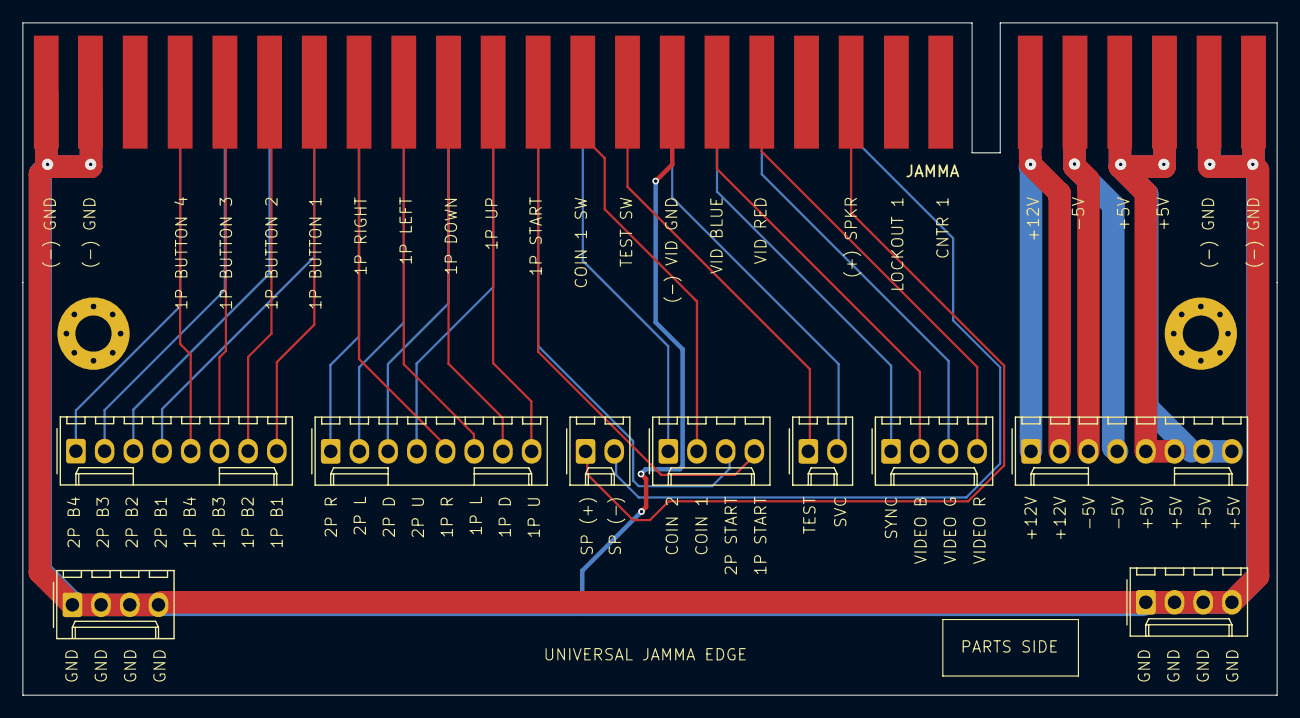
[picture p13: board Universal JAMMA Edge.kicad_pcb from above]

Board: 2 copper layers, 111.0 x 59.5 mm, 4 parts (0 on the bottom side), 4 nets.

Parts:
Ground: Molex_KK-254_AE-6410-04A_1x04_P2.54mm_Vertical
Ground#2: Molex_KK-254_AE-6410-04A_1x04_P2.54mm_Vertical
JAMMA: HDR_JAMMA_56P_EDGE_CONNECTOR
Power: Molex_KK-254_AE-6410-08A_1x08_P2.54mm_Vertical

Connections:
+5V: JAMMA.3, JAMMA.4, JAMMA.C, JAMMA.D, Power.5, Power.6, Power.7, Power.8
+12V: JAMMA.6, JAMMA.F, Power.1, Power.2
-5V: JAMMA.5, JAMMA.E, Power.3, Power.4
GND: Ground.1, Ground.2, Ground.3, Ground.4, Ground#2.1, Ground#2.2, Ground#2.3, Ground#2.4, JAMMA.1, JAMMA.2, JAMMA.14, JAMMA.27, JAMMA.28, JAMMA.A, JAMMA.B, JAMMA.e, JAMMA.f

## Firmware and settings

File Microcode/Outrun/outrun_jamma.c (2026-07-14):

/*
 * @file outrun_jamma.c
 * @brief Sega Outrun Rev. B to JAMMA Adapter Firmware
 * 
 * This firmware controls the ATMEGA328P microcontroller to interface
 * between JAMMA inputs and analog voltage outputs via MCP4902 DAC.
 * 
 * Pin Assignments:
 * Inputs (active-low with internal pull-ups):
 *   PD2 (Pin 4)  - B1 (Accelerate), enabled adjustable VOUTA
 *   PD3 (Pin 5)  - B2 (Shift, toggle or momentary per SHIFT_MODE)
 *   PD4 (Pin 6)  - B3 (Brake), digital H/L output
 *   PD5 (Pin 11) - UP, Increases accelerator voltage
 *   PD6 (Pin 12) - DOWN, Decreases accelerator voltage
 *   PD7 (Pin 13) - LEFT, Decreases steering voltage
 *   PB0 (Pin 14) - RIGHT, Increases steering voltage
 * 
 * Outputs:
 *   PB1 (Pin 15) - B3_OUT (Brake, HIGH or LOW)
 *   PB2 (Pin 16) - B2_OUT (Shift output; latched toggle or momentary per SHIFT_MODE)
 *   PB3 (Pin 17) - MCP4902 CS
 *   PB4 (Pin 18) - MCP4902 SDI
 *   PB5 (Pin 19) - MCP4902 SCK
 * 
 * DAC Outputs:
 *   VOUTA (Pin 14 on MCP4902), Accelerator voltage
 *   VOUTB (Pin 10 on MCP4902), Steering voltage
 */

#define F_CPU 8000000UL

#include <avr/io.h>
#include <avr/interrupt.h>
#include <util/delay.h>
#include "outrun_jamma.h"

#define DEBOUNCE_DELAY_MS       20
#define BUTTON_REPEAT_DELAY_MS  300
#define BUTTON_REPEAT_RATE_MS   31      /* ~2s full sweep: 300ms delay + 54 steps * 31ms */

/* Steering button repeat: 80ms delay then 25ms (~40Hz) per step.
 * With step=2, full lock (76 units) takes ~80 + 38*25 = ~1s. */
#define STEERING_BUTTON_REPEAT_DELAY_MS   0
#define STEERING_BUTTON_REPEAT_RATE_MS    0.75

/*
 * Accelerator Pedal DAC Constants
 * Voltage step size (~19.6mV per step)
 * From manual: Valid pedal ranges 32-146
 */

#define ACCEL_ADJUST_STEP         2    /* ~98mV per step */
#define ACCEL_MIN_VALUE           32
#define ACCEL_MAX_VALUE           146

/*
 * Steering DAC Constants - Game-recognized range (51-203), Zeroed @ 128
 * Voltage step size (~19.6mV per step)
 */

#define STEERING_ADJUST_STEP      1     /* ~39mV per step for smooth steering */
#define STEERING_MIN_VALUE        51
#define STEERING_MAX_VALUE        203
#define STEERING_MID_VALUE  	  128
#define STEERING_RETURN_DIVISOR   16    /* Proportional return: step = distance/16
                                         * (4 steps at full lock, 1 step near center) */
#define STEERING_RETURN_RATE_MS    2    /* Throttle return-to-center: ~12ms between
                                         * steps gives ~230ms full-lock-to-center,
                                         * matching a real spring-loaded wheel */

/* Loop Timing; MCP4902 settling time is 4.5us, 20us safe for smooth updates */
#define LOOP_TIME_MS    0.05
#define MS_TO_LOOPS(ms) ((uint32_t)((ms)/LOOP_TIME_MS))

/*
 * Pin Definitions
 */

/* Input pins, Active-Low */
#define B1_PIN_BIT              PD2     // Accelerate     - Pin 4  (INT0)
#define B2_PIN_BIT              PD3     // Shift toggle   - Pin 5  (INT1)
#define B3_PIN_BIT              PD4     // Brake          - Pin 6  (XCK/T0)
#define UP_PIN_BIT              PD5     // Increase accel - Pin 11 (T1)
#define DOWN_PIN_BIT            PD6     // Decrease accel - Pin 12 (AIN0)
#define LEFT_PIN_BIT            PD7     // Decrease steer - Pin 13 (AIN1)
#define RIGHT_PIN_BIT           PB0     // Increase steer - Pin 14 (ICP1)

/* Output pins */
#define B3_OUT_PIN_BIT          PB1     // Brake output - Pin 15 (OC1A)
#define B2_OUT_PIN_BIT          PB2     // Shift output - Pin 16 (SS/OC1B)
#define MCP_CS_PIN_BIT          PB3     // DAC CS  - Pin 17 to MCP4902 Pin 3
#define MCP_SD_PIN_BIT          PB4     // DAC SDI - Pin 18 to MCP4902 Pin 5
#define MCP_SCK_PIN_BIT         PB5     // DAC SCK - Pin 19 to MCP4902 Pin 4

/*
 * B2 (Shift) Output Mode
 * ----------------------
 * The hi/lo shifter input (B2) is mapped to a digital output (PB2). Two
 * behaviors are selectable at compile time:
 *
 *   SHIFT_MODE_TOGGLE     (default) Latching toggle: each confirmed press
 *                         flips the output between HIGH and LOW (hi/lo gear).
 *                         Matches the original Outrun shifter.
 *
 *   SHIFT_MODE_MOMENTARY  Output follows the debounced button directly: HIGH
 *                         while held, LOW when released. Use this for titles
 *                         that repurpose the shifter as a momentary "turbo"
 *                         button.
 *
 * Select at build time, e.g.:
 *   make SHIFT_MODE=SHIFT_MODE_MOMENTARY
 */
#define SHIFT_MODE_TOGGLE     0
#define SHIFT_MODE_MOMENTARY  1

#ifndef SHIFT_MODE
#define SHIFT_MODE SHIFT_MODE_TOGGLE
#endif

/* Globals */
static uint8_t accel_voltage_value    = ACCEL_MAX_VALUE;
static uint8_t steering_voltage_value = STEERING_MID_VALUE;
static uint8_t last_steering_dac_value = 0xFF;              /* Sentinel: forces first write */
#if (SHIFT_MODE == SHIFT_MODE_TOGGLE)
static uint8_t b2_toggle_state        = 1;                  // Shift latch (L)
#endif
static uint8_t brake_pressed_state    = 0;                  // Brake (L)

/* Globals for button repeat timing */
static uint32_t up_last_press_time    = 0;
static uint32_t down_last_press_time  = 0;
static uint32_t left_last_press_time  = 0;
static uint32_t right_last_press_time = 0;

/* Accelerator ramp target: full throttle on B1 press, idle on release.
 * Adjustable via UP/DOWN while B1 is held to set a partial-throttle setpoint. */
static uint8_t accel_ramp_target      = ACCEL_MIN_VALUE;

/* Steering button state tracking for separate repeat timing */
static uint8_t left_steering_pressed  = 0;
static uint8_t right_steering_pressed = 0;

static volatile uint32_t loop_counter = 0;

int main(void)
{
    /* Power-on delay, ensure JAMMA power rails are stabile */
    _delay_ms(500);
    
    system_init();
    
    /* Initialize DAC outputs */
    update_accel_voltage(accel_voltage_value);
    update_steering_voltage(steering_voltage_value);
    
    /* Main event loop */
    while (1) {
        update_outputs();
        _delay_us(50);
        loop_counter++;
    }
    
    return 0;
}

void system_init(void)
{
    gpio_init();
    spi_init();
    
    /* Disable global interrupts (Unnecessary) */
    cli();
}

/*
 * Initialize GPIO Pins
 * Configures all input and output pins.
 * Inputs use internal pull-ups for active-low logic.
 * Outputs are configured as push-pull digital.
 * SPI uses PB3=CS, PB4=SDI, PB5=SCK
 */

void gpio_init(void)
{
    /* Configure input pins with internal pull-ups for active-low */
    DDRD &= ~(1 << PD2);  // B1 (Accelerate)   - Pin 4
    DDRD &= ~(1 << PD3);  // B2 (Shift toggle) - Pin 5
    DDRD &= ~(1 << PD4);  // B3 (Brake)        - Pin 6
    DDRD &= ~(1 << PD5);  // UP                - Pin 11
    DDRD &= ~(1 << PD6);  // DOWN              - Pin 12
    DDRD &= ~(1 << PD7);  // LEFT              - Pin 13
    DDRB &= ~(1 << PB0);  // RIGHT             - Pin 14
    
    /* Enable pull-ups */
    PORTD |= (1 << PD2);  // B1
    PORTD |= (1 << PD3);  // B2
    PORTD |= (1 << PD4);  // B3
    PORTD |= (1 << PD5);  // UP
    PORTD |= (1 << PD6);  // DOWN
    PORTD |= (1 << PD7);  // LEFT
    PORTB |= (1 << PB0);  // RIGHT
    
    /* Configure output pins as push-pull digital */
    DDRB |= (1 << PB1);   // B3_OUT (Brake) - Pin 15
    PORTB &= ~(1 << PB1); // LOW (Default State)
    
    DDRB |= (1 << PB2);   // B2_OUT (Shift) - Pin 16
    PORTB &= ~(1 << PB2); // LOW (Default State)
    
    /* Configure SPI pins for MCP4902 */
    DDRB |= (1 << PB3);   // CS
    PORTB |= (1 << PB3);  // CS HIGH (Initially deselect DAC)
    
    DDRB |= (1 << PB4);   // SDI, Output for SPI Data
    PORTB &= ~(1 << PB4); // LOW (Default State)
    
    DDRB |= (1 << PB5);   // SCK, Output for SPI Clock
    PORTB &= ~(1 << PB5); // LOW (Default State)
}

/* Disables hardware SPI in favor of PB3/PB4/PB5 */

void spi_init(void)
{
    SPCR = 0;
    SPSR = 0;
}

/*
 * MCP4902 DAC Write Function
 * Sends command and 8-bit data to MCP4902 via SW SPI.
 * PB3=CS, PB4=SDI, PB5=SCK
 * 
 * @param CH 0 for VOUTA, CH 1 for VOUTB
 * @param data 8-bit DAC value (0-255)
 */

void mcp4902_write(uint8_t channel, uint8_t data)
{
    uint16_t command_word;
    uint8_t i;
    
    if (channel == 0) // VOUTA
    {
        command_word = 0x3000 | (data << 4);
    } else            // VOUTB
    {
        command_word = 0xB000 | (data << 4);
    }
    
    /* Assert CS */
    PORTB &= ~(1 << MCP_CS_PIN_BIT);
    
    /* Send 16 bits MSB first */
    for (i = 0; i < 16; i++)
    {
        /* Set SDI to current bit */
        if (command_word & 0x8000)
        {
            PORTB |= (1 << MCP_SD_PIN_BIT);   // HIGH
        } else
        {
            PORTB &= ~(1 << MCP_SD_PIN_BIT);  // LOW
        }
        
        /* Pulse SCK - MCP4902 accepts up to 20MHz SCK; AVR GPIO toggle
         * (~125ns) is well above the 50ns min pulse width. */
        PORTB |= (1 << MCP_SCK_PIN_BIT);
        PORTB &= ~(1 << MCP_SCK_PIN_BIT);
        
        /* Shift to next bit */
        command_word <<= 1;
    }
    
    /* Deassert CS */
    PORTB |= (1 << MCP_CS_PIN_BIT);
}

/*
 * Update Accelerator Pedal Voltage (VOUTA)
 * Writes to the DAC CH A output with the specified value (0-5v) (0-255).
 * When B1 is pressed, current accelerator value is written
 * When B1 not pressed, ACCEL_MIN_VALUE is written
 *
 * @param value 8-bit DAC value (0-255)
 */

void update_accel_voltage(uint8_t value)
{
    if (value > ACCEL_MAX_VALUE)
    {
        value = ACCEL_MAX_VALUE;
    }
    
    accel_voltage_value = value;
    
    /* Write to MCP4902 CH 0 (VOUTA) */
    mcp4902_write(0, value);
}

/*
 * Update Steering Voltage (VOUTB)
 * Writes to the DAC CH B output with the specified value, 0-5v (0-255).
 * When neither L/R are pressed, STEERING_MID_VALUE is written 
 *
 * @param value 8-bit DAC value (0-255)
 */

void update_steering_voltage(uint8_t value) {
    if (value > STEERING_MAX_VALUE)
    {
        value = STEERING_MAX_VALUE;
    }

    steering_voltage_value = value;

    /* Skip DAC write if value hasn't changed (e.g. clamped at MAX/MIN) */
    if (value != last_steering_dac_value) {
        mcp4902_write(1, value);
        last_steering_dac_value = value;
    }
}

/*
 * Read Button State
 * Reads a button input and returns 1 if pressed (active-low), 0 otherwise.
 * 
 * @param port Pointer to port register (PIND or PINB)
 * @param bit  Bit position within the port
 * @return 1 if button pressed, 0 if not pressed
 */

uint8_t read_button(volatile uint8_t *port, uint8_t bit)
{
    return !(*port & (1 << bit));
}

/*
 * Set Brake Output State
 * Sets the brake output pin (PB1) to HIGH or LOW.
 * This is a PUSH-PULL digital output to drive 5v and 0v directly.
 * 
 * NOTE: This would normally be DAC values 32 or 208,8
 *       but we don't have a third DAC channel.
 *
 * @param state 1 for HIGH (5V), 0 for LOW (0V)
 */

void set_brake_output(uint8_t state)
{
    if (state)
    {
        PORTB |= (1 << B3_OUT_PIN_BIT);   // HIGH (5v)
    } else
    {
        PORTB &= ~(1 << B3_OUT_PIN_BIT);  // LOW  (0v)
    }
}

/*
 * Set Shift Output State
 * Sets the shift output pin (PB2) to HIGH or LOW.
 * This is a PUSH-PULL digital output to drive 5v and 0v directly.
 * 
 * @param state 1 for HIGH (5V), 0 for LOW (0V)
 */

void set_shift_output(uint8_t state)
{
    if (state)
    {
        PORTB |= (1 << B2_OUT_PIN_BIT);   // HIGH (5v)
    } else
    {
        PORTB &= ~(1 << B2_OUT_PIN_BIT);  // LOW  (0v)
    }
}

/*
 * Update All Outputs
 * Main output update function called in the main loop. Handles:
 * - B1 (Accelerate): Enables VOUTA, UP/DOWN adjust voltage when pressed
 * - B2 (Shift): Single digital output PB2, HIGH or LOW based on toggle
 * - B3 (Brake): Digital output PB1, HIGH when pressed, LOW when not
 * - LEFT/RIGHT: Adjusts steering voltage (VOUTB)
 * 
 * Implements debouncing and button repeat functionality
 */

void update_outputs(void)
{
    static uint8_t b1_state = 0;
    
    /* B1: Accelerate Button, enabled VOUTA voltage */

    if (read_button(&PIND, B1_PIN_BIT))
    { 
        if (! b1_state)
        {
            b1_state = 1;

            /* Ramp target is full throttle when pedal is pressed */
            accel_ramp_target = ACCEL_MAX_VALUE;
        }
    } else {
        if (b1_state)
        {
            b1_state = 0;

            /* Ramp down to minimum when pedal released */
            accel_ramp_target = ACCEL_MIN_VALUE;
        } else {
            update_accel_voltage(ACCEL_MIN_VALUE);
        }
    }

    /* Accelerator ramp smoothing: tracks accel_ramp_target at 2 steps/loop
     * (~196mV/ms) in either direction, so UP/DOWN setpoint changes while
     * B1 is held are followed smoothly rather than overridden. */
    if (accel_voltage_value < accel_ramp_target)
    {
        accel_voltage_value += 2;
        if (accel_voltage_value > accel_ramp_target)
        {
            accel_voltage_value = accel_ramp_target;
        }

        update_accel_voltage(accel_voltage_value);

    } else if (accel_voltage_value > accel_ramp_target)
    {
        accel_voltage_value -= 2;
        if (accel_voltage_value < accel_ramp_target) {
            accel_voltage_value = accel_ramp_target;
        }
        update_accel_voltage(accel_voltage_value);
    }

    /* B2: Shift, Digital Output (latched toggle or momentary per SHIFT_MODE) */

    static uint8_t b2_confirmed_state = 0;
    static uint8_t b2_raw_last = 0;
    static uint32_t b2_debounce_counter = 0;
    uint8_t b2_current = read_button(&PIND, B2_PIN_BIT);

    /* Debounce Detection */
    if (b2_current != b2_raw_last) {
        b2_debounce_counter = 0;
        b2_raw_last = b2_current;
    } else {
        b2_debounce_counter++;
    }

    if (b2_debounce_counter == MS_TO_LOOPS(DEBOUNCE_DELAY_MS)) {
        if (b2_current != b2_confirmed_state) {
            b2_confirmed_state = b2_current;
#if (SHIFT_MODE == SHIFT_MODE_MOMENTARY)
            /* Momentary: output tracks the debounced button directly.
             * HIGH while held, LOW when released (turbo button). */
            set_shift_output(b2_current);
#else
            /* Toggle: flip the latch on each confirmed press only. */
            if (b2_current == 1) {  // Only toggle on press, not release
                b2_toggle_state = !b2_toggle_state;
                set_shift_output(b2_toggle_state);
            }
#endif
        }
    }
    
    /* B3: Brake, Digital Output */

    if (read_button(&PIND, B3_PIN_BIT))
    {
        if (! brake_pressed_state)
        {
            brake_pressed_state = 1;
            set_brake_output(1);  // HIGH (5v)
        }
    } else
    {
        if (brake_pressed_state) {
            brake_pressed_state = 0;
            set_brake_output(0);  // LOW (0v)
        }
    }
    
    /* UP/DOWN: Adjust Accelerator Voltage when B1 is Pressed */
    
    static uint8_t up_pressed = 0;
    static uint8_t down_pressed = 0;
    static uint8_t up_repeating = 0;
    static uint8_t down_repeating = 0;
    
    /* UP: Increase accelerator voltage */

    if (read_button(&PIND, UP_PIN_BIT))
    {
        if (! up_pressed)
        {
            if (b1_state)
            {
                accel_ramp_target += ACCEL_ADJUST_STEP;
                if (accel_ramp_target > ACCEL_MAX_VALUE)
                {
                    accel_ramp_target = ACCEL_MAX_VALUE;
                }
            }
            up_pressed = 1;
            up_repeating = 0;
            up_last_press_time = loop_counter;
        } else if (b1_state)
        {
            uint32_t up_threshold = up_repeating ? MS_TO_LOOPS(BUTTON_REPEAT_RATE_MS)
                                                  : MS_TO_LOOPS(BUTTON_REPEAT_DELAY_MS);

            if (loop_counter - up_last_press_time >= up_threshold)
            {
                accel_ramp_target += ACCEL_ADJUST_STEP;
                up_last_press_time = loop_counter;
                up_repeating = 1;

                if (accel_ramp_target > ACCEL_MAX_VALUE)
                {
                    accel_ramp_target = ACCEL_MAX_VALUE;
                }
            }
        }
    } else {
        up_pressed = 0;
        up_repeating = 0;
    }
    
    /* DOWN: Decrease accelerator voltage */

    if (read_button(&PIND, DOWN_PIN_BIT))
    {
        if (! down_pressed)
        {
            if (b1_state)
            {
                if (accel_ramp_target >= ACCEL_MIN_VALUE + ACCEL_ADJUST_STEP)
                {
                    accel_ramp_target -= ACCEL_ADJUST_STEP;
                } else {
                    accel_ramp_target = ACCEL_MIN_VALUE;
                }
            }
            down_pressed = 1;
            down_repeating = 0;
            down_last_press_time = loop_counter;
        } else if (b1_state)
        {
            uint32_t down_threshold = down_repeating ? MS_TO_LOOPS(BUTTON_REPEAT_RATE_MS)
                                                       : MS_TO_LOOPS(BUTTON_REPEAT_DELAY_MS);

            if (loop_counter - down_last_press_time >= down_threshold)
            {
                down_last_press_time = loop_counter;
                down_repeating = 1;

                if (accel_ramp_target >= ACCEL_MIN_VALUE + ACCEL_ADJUST_STEP)
                {
                    accel_ramp_target -= ACCEL_ADJUST_STEP;
                } else {
                    accel_ramp_target = ACCEL_MIN_VALUE;
                }
            }
        }
    } else {
        down_pressed = 0;
        down_repeating = 0;
    }
    
    /* Steering Voltage (VOUTB) - LEFT/RIGHT debounced like B2 */

    static uint8_t left_pressed = 0;
    static uint8_t right_pressed = 0;
    static uint8_t left_debounced = 0;
    static uint8_t left_raw_last = 0;
    static uint32_t left_debounce_counter = 0;
    static uint8_t right_debounced = 0;
    static uint8_t right_raw_last = 0;
    static uint32_t right_debounce_counter = 0;

    /* Debounce RIGHT (PB0) */
    uint8_t right_raw = read_button(&PINB, RIGHT_PIN_BIT);
    if (right_raw != right_raw_last) {
        right_debounce_counter = 0;
        right_raw_last = right_raw;
    } else {
        right_debounce_counter++;
    }
    if (right_debounce_counter >= MS_TO_LOOPS(DEBOUNCE_DELAY_MS)) {
        right_debounced = right_raw;
    }

    /* RIGHT: Increase steering voltage toward STEERING_MAX_VALUE */
    if (right_debounced)
    {
        right_steering_pressed = 1;

        if (! right_pressed) {
            steering_voltage_value += STEERING_ADJUST_STEP;
            if (steering_voltage_value > STEERING_MAX_VALUE)
            {
                steering_voltage_value = STEERING_MAX_VALUE;
            }
            update_steering_voltage(steering_voltage_value);
            right_pressed = 1;
            right_last_press_time = loop_counter;
        } else if ((loop_counter - right_last_press_time
                    >= MS_TO_LOOPS(STEERING_BUTTON_REPEAT_DELAY_MS)))
        {
            if (loop_counter - right_last_press_time >= MS_TO_LOOPS(STEERING_BUTTON_REPEAT_RATE_MS))
            {
                steering_voltage_value += STEERING_ADJUST_STEP;
                right_last_press_time = loop_counter;
                if (steering_voltage_value > STEERING_MAX_VALUE)
                {
                    steering_voltage_value = STEERING_MAX_VALUE;
                }
                update_steering_voltage(steering_voltage_value);
            }
        }
    } else {
        right_pressed = 0;
        right_steering_pressed = 0;
    }

    /* Debounce LEFT (PD7) */
    uint8_t left_raw = read_button(&PIND, LEFT_PIN_BIT);
    if (left_raw != left_raw_last) {
        left_debounce_counter = 0;
        left_raw_last = left_raw;
    } else {
        left_debounce_counter++;
    }
    if (left_debounce_counter >= MS_TO_LOOPS(DEBOUNCE_DELAY_MS)) {
        left_debounced = left_raw;
    }

    /* LEFT: Decrease steering voltage toward STEERING_MIN_VALUE */
    if (left_debounced)
    {
        left_steering_pressed = 1;

        if (! left_pressed)
        {
            if (steering_voltage_value >= STEERING_MIN_VALUE + STEERING_ADJUST_STEP)
            {
                steering_voltage_value -= STEERING_ADJUST_STEP;
            } else {
                steering_voltage_value = STEERING_MIN_VALUE;
            }

            update_steering_voltage(steering_voltage_value);
            left_pressed = 1;
            left_last_press_time = loop_counter;
        } else if (loop_counter - left_last_press_time >= MS_TO_LOOPS(STEERING_BUTTON_REPEAT_DELAY_MS))
        {
            if (loop_counter - left_last_press_time >= MS_TO_LOOPS(STEERING_BUTTON_REPEAT_RATE_MS))
            {
                left_last_press_time = loop_counter;
                if (steering_voltage_value >= STEERING_MIN_VALUE + STEERING_ADJUST_STEP)
                {
                    steering_voltage_value -= STEERING_ADJUST_STEP;
                } else {
                    steering_voltage_value = STEERING_MIN_VALUE;
                }

                update_steering_voltage(steering_voltage_value);
            }
        }
    } else {
        left_pressed = 0;
        left_steering_pressed = 0;
    }

    /* Smoothly center steering when neither L/R is held.
     * Proportional step (distance/16, min 1) gives faster return far from
     * center, slower near it. Throttled to STEERING_RETURN_RATE_MS so the
     * full-lock-to-center sweep takes ~230ms instead of ~2ms. */
    if (! left_steering_pressed && ! right_steering_pressed)
    {
        static uint32_t last_return_loop = 0;

        if (loop_counter - last_return_loop >= MS_TO_LOOPS(STEERING_RETURN_RATE_MS))
        {
            last_return_loop = loop_counter;

            if (steering_voltage_value > STEERING_MID_VALUE)
            {
                uint8_t distance = steering_voltage_value - STEERING_MID_VALUE;
                uint8_t return_step = distance / STEERING_RETURN_DIVISOR;
                if (return_step < 1) return_step = 1;
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

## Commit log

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2025-11-01 0x8c is expressed as 2s complement, not 1s complement
    [Spy Hunter JAMMA Adapter.kicad_pcb]
2025-11-01 add pull-down resistor for U7
    [Spy Hunter JAMMA Adapter.kicad_pcb]
2025-11-02 cause high counter to disable low counter on max/min to give us 4 bits of cushion
    [Spy Hunter JAMMA Adapter.kicad_pcb]
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2025-11-03 add R26, consolidate R10 as 220R
    [Spy Hunter JAMMA Adapter.csv]
2025-11-10 Use 3.96mm header for J1
    [TRON to JAMMA Adapter.kicad_pcb]
2025-11-10 update TRON rev 1 BOM
    [TRON to JAMMA Adapter, Rev1.csv]
2025-11-12 3.96 for power, rework board a bit
    [Spy Hunter JAMMA Adapter.kicad_pcb]
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2025-11-12 update BOM and snapshots
    [Spy Hunter JAMMA Adapter, Rev0.csv, Spy Hunter JAMMA Adapter, Rev1.csv, Spy Hunter JAMMA Adapter.kicad_pcb]
2025-11-13 use right angle 3.96 molex headers
    [Spy Hunter JAMMA Adapter, Rev1.csv]
2025-11-13 get rid of unnecessary pull-ups
    [Spy Hunter JAMMA Adapter.kicad_pcb]
2025-11-14 reposition kick harness connector
    [Spy Hunter JAMMA Adapter.kicad_pcb]
2025-11-15 swap initial/final pins of P3
    [Spy Hunter JAMMA Adapter.kicad_pcb]
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2025-11-15 correct polarity of trim pots
    [Spy Hunter JAMMA Adapter.kicad_pcb]
2025-11-15 minor cleanup and fine tuning
    [Spy Hunter JAMMA Adapter.kicad_pcb]
2025-11-15 move some resistor names around
    [Spy Hunter JAMMA Adapter, Rev1.csv, Spy Hunter JAMMA Adapter.kicad_pcb]
2025-11-19 Add right-angle connector part for J1
    [TRON to JAMMA Adapter, Rev1.csv]
2025-11-19 switch to black guard
    [Spy Hunter JAMMA Adapter, Rev1.csv]
2025-11-19 straight 3.96 for Spy Hunter, right angle for Tron
    [Spy Hunter JAMMA Adapter, Rev1.csv, TRON to JAMMA Adapter.kicad_pcb]
2025-11-19 update snapshots, tweak vias
    [TRON to JAMMA Adapter.kicad_pcb]
2025-11-20 move connectors up, rework vias a bit, update text
    [TRON to JAMMA Adapter.kicad_pcb]
2025-11-21 add CHAMMA (six button) interface
    [Universal CHAMMA Interface.kicad_pcb]
2025-11-21 rename document, add snapshots
    [Universal CHAMMA Interface.kicad_pcb]
2025-11-22 place 555 and 34063 correctly on silkscreen
    [RoadBlasters JAMMA Adapter.kicad_pcb]
2025-11-23 template for microcontroller jamma interface
    [Universal JAMMA Microcontroller.kicad_pcb]
2025-11-23 rename some more things
    [Universal JAMMA Interface.kicad_pcb]
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2025-11-23 fix name
    [Universal JAMMA Microcontroller.kicad_pcb]
2025-11-23 add microcontroller edge adapter
    [JAMMA Microcontroller Adapter.kicad_pcb]
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2025-11-26 correct RVR/RV12 effects labels, swap music pot around
    [Spy Hunter JAMMA Adapter.kicad_pcb]
2025-11-26 power connections -> 3.96mm
    [Atari JAMMA Interface.kicad_pcb]
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2025-11-29 clear a red path to pins
    [Universal JAMMA Microcontroller.kicad_pcb]
2025-11-30 Williams System JAMMA Rev. 1
    [Williams JAMMA Interface.kicad_pcb]
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2025-12-02 slightly move ground in
    [Atari JAMMA Interface.kicad_pcb]
2025-12-03 the tiniest little silkscreen tweak
    [Spy Hunter JAMMA Adapter.kicad_pcb]
2025-12-03 tighten up font sizes and positioning for text inside components
    [Atari JAMMA Interface.kicad_pcb, RoadBlasters JAMMA Adapter.kicad_pcb, Universal JAMMA Interface.kicad_pcb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]
2025-12-04 22R for 10K pot, use 2A152J for 152 (reduces noise)
    [Atari JAMMA Interface.kicad_pcb]
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2025-12-04 152 changed to 2a152j (reduced noise), other tweaks
    [RoadBlasters JAMMA Adapter.kicad_pcb]
2025-12-04 152 becomes 2A152J (reduced noise)
    [JAMMA Microcontroller Adapter.kicad_pcb]
2025-12-04 152 becomes 2A152J (reduces noise)
    [Universal JAMMA Microcontroller.kicad_pcb]
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2025-12-09 add jumper to select button 2 behavior: gas or brake
    [RoadBlasters JAMMA Adapter.kicad_pcb]
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2025-12-22 add fifth ground contact to 3.96mm connector
    [Atari JAMMA Interface.kicad_pcb]
2025-12-22 add video ground, replace 2.54mm grounds with 3.96
    [Atari JAMMA Interface.kicad_pcb]
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2025-12-23 minor tweaks to inductor
    [Atari JAMMA Interface.kicad_pcb]
2025-12-24 reduce form factor of C7, tweak layout and silkscreen
    [Williams JAMMA Interface.kicad_pcb]
2025-12-24 slight tweaks to layout and silkscreen
    [Atari JAMMA Interface.kicad_pcb]
2025-12-24 more slight silkscreen tweaks
    [Williams JAMMA Interface.kicad_pcb]
2025-12-24 chamma compat, add b5/b6 and pins for level up/dn on dot
    [TRON to JAMMA Adapter.kicad_pcb]
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2025-12-29 minor silkscreen tweaks, new snapshots
    [TRON to JAMMA Adapter.kicad_pcb]
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2026-01-08 3.4mm film caps for 152
    [Atari JAMMA Interface.kicad_pcb, RoadBlasters JAMMA Adapter.kicad_pcb, Williams JAMMA Interface.kicad_pcb]
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2026-01-09 remove random + sign from silkscreen
    [Spy Hunter JAMMA Adapter.kicad_pcb]
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2026-01-10 i made a BOM
    [Atari JAMMA Interface.csv]
2026-01-10 some rando on the internet didn't like how this was routed
    [RoadBlasters JAMMA Adapter.kicad_pcb]
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2026-05-10 improve decoupling, cleanup trace
    [Blasteroids JAMMA Adapter.kicad_pcb]
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2026-05-13 reverse A/B on AMP50 and AMP20
    [Outrun JAMMA Adapter.kicad_pcb]
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2026-05-13 add pcb, minor tweaking
    [Outrun JAMMA Adapter.kicad_pcb]
2026-05-13 minor cleanup, populated image
    [Outrun JAMMA Adapter.kicad_pcb]
2026-05-13 add pin 1 labels
    [Outrun JAMMA Adapter.kicad_pcb]
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2026-05-13 DAC gain was actually correct
    [outrun_jamma.c]
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2026-05-14 steering smoothness and other fixes
    [outrun_jamma.c]
2026-05-19 add relief for size of AMP connectors
    [Outrun JAMMA Adapter.kicad_pcb]
2026-05-25 Add JAMMA Schematic Component
    [HDR_JAMMA_56P_EDGE_CONNECTOR.kicad_sch]
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2026-06-15 fixed and tested code
    [outrun_jamma.c]
2026-06-15 remap pins for ribbon cable, change audio/video to larger connector
    [Outrun JAMMA Adapter.kicad_pcb]
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2026-06-15 fix bug in up/dn speed adjustment
    [outrun_jamma.c]
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2026-06-16 Move bottom ribbon to center to avoid ribbon damage, make connector labels larger
    [Outrun JAMMA Adapter.kicad_pcb]
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2026-06-16 remove tooling holes (0.2 precision), add space
    [Outrun JAMMA Adapter.kicad_pcb]
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2026-06-17 better silkscreen placement for title
    [Outrun JAMMA Adapter.kicad_pcb]
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2026-06-26 align pin 1 of 2x10s on silkscreen, flip all connectors around for easier mounting
    [Outrun JAMMA Adapter.kicad_pcb]
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2026-07-06 move the mounting holes in just a smidge
    [Outrun JAMMA Adapter.kicad_pcb]
2026-07-06 Organize projects into various folders
    [Atari JAMMA Interface.csv, Outrun JAMMA Adapter.csv, RoadBlasters JAMMA Adapter, Rev0.csv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]
2026-07-06 Organize CAD files into separate folder
    [Atari JAMMA Interface.kicad_pcb, Blasteroids JAMMA Adapter.kicad_pcb, HDR_JAMMA_56P_EDGE_CONNECTOR.kicad_sch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]
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2026-07-10 Switch D and G IDC connectors to prevent chafing
    [Outrun JAMMA Adapter.kicad_pcb]
2026-07-12 Spy Hunter Rev. 1.1 (Under Development, Untested)
    [Spy Hunter JAMMA Adapter.kicad_pcb]
2026-07-13 Put component values on silkscreen R12/R13
    [Spy Hunter JAMMA Adapter.kicad_pcb]
2026-07-13 Fix dupe of C13, rename second one to C20
    [Spy Hunter JAMMA Adapter.kicad_pcb]
2026-07-13 R3 can be 2K2 for better log trim
    [RoadBlasters JAMMA Adapter.kicad_pcb]
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2026-07-15 trim shunt -> 2K2
    [TRON to JAMMA Adapter.kicad_pcb]
2026-07-31 R3 audio taper, 22R -> 2.2K
    [Atari JAMMA Interface.kicad_pcb]
2026-08-15 Add Super Hang-On PCB
    [Super Hang-On JAMMA Adapter.kicad_pcb]
2026-08-15 Adjust positioning of 50-pin, move text to bottom, slight tweaks
    [Super Hang-On JAMMA Adapter.kicad_pcb]

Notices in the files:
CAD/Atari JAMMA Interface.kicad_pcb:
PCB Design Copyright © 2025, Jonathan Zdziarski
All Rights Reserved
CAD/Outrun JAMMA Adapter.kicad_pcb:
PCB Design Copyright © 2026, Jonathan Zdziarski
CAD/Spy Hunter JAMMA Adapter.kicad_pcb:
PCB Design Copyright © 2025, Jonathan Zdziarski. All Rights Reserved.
